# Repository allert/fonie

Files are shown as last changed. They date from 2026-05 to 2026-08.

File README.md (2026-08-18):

# 🎵 Fonie - RFID Spotify Player

ESP32 + Raspberry Pi + PN532 NFC reader = automated Spotify playback

## Hardware
- **ESP32 WROOM** - RFID polling via I2C
- **PN532** - NFC/RFID reader (I2C mode)
- **Raspberry Pi 4** - Flask web UI + Spotify integration

## Quick Start

### Fresh Pi Setup
```bash
git clone https://github.com/YOUR_USERNAME/fonie.git
cd fonie
chmod +x setup.sh
./setup.sh
```

### Manual Setup
1. Raspberry Pi OS 64-bit
2. `pip3 install -r requirements.txt`
3. Edit `.env` with Spotify credentials
4. `systemctl start fonie`
5. Visit `http://fonie.local`

## Files
- `app.py` - Flask backend
- `setup.sh` - Automated setup script
- `templates/index.html` - Web UI
- `esp32/esp.ino` - ESP32 firmware

## Configuration
1. Get Spotify API credentials from [developer.spotify.com](https://developer.spotify.com)
2. Set in `.env`:
```
   SPOTIFY_CLIENT_ID=...
   SPOTIFY_CLIENT_SECRET=...
```

## ESP32 JSON Protocol
```json
{"event":"TAG_ON","uid":"4F02FB46F6180"}
{"event":"TAG_OFF","uid":"4F02FB46F6180"}
```

## License
MIT

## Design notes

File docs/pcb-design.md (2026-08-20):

# Fonie — Custom Carrier PCB Design Specification 🛠️📐

This document outlines the complete schematic architecture, component selection (BOM), connector layout, and KiCad design guide for creating a single, professional **Fonie Mainboard Carrier PCB**.

---

## 🎯 Objectives & Benefits

1. **Zero Point-to-Point Wiring Harnesses:** Replaces loose wires, crimp pins, and protoboards with a clean 2-layer PCB.
2. **Direct Raspberry Pi 4 Docking:** Features a female 2×20 GPIO socket header that docks directly onto the Pi 4.
3. **Integrated Compute Nodes:** Sockets/footprints for:
   - **RP2040 Zero** (Waveshare module or stamp footprint)
   - **ESP32-C3 SuperMini** (or ESP32-C3-WROOM module)
   - **INA226 I2C Battery Telemetry Sensor**
4. **Onboard Power Management:**
   - Onboard Pololu 2808 soft switch connector / circuit
   - High-efficiency 5V 3A Synchronous Step-Down Buck Converter (e.g., MP2307 / TPS54331)
5. **Clean Polarized Connectors:**
   - **JST-PH 2.0mm / 2.54mm headers** for 5× Front Buttons, NeoPixel Matrix, NeoPixel Ring, Left/Right Surround LED Strips, and PN532 NFC scanner.

---

## 🏗️ Schematic Block Diagram

```
                 3S Li-ion Battery Pack (9.0V – 12.6V)
                                │
                                ▼
                       ┌────────────────┐
                       │  INA226 Sensor │  (I2C to Pico)
                       └───────┬────────┘
                               │
                               ▼
                       ┌────────────────┐
                       │  Pololu 2808   │  ◄── Vol Up Button (A pin)
                       │  Soft Switch   │  ◄── Pico GP14 (OFF pin)
                       └───────┬────────┘
                               │ Switched 12V (VOUT)
                               ▼
            ┌──────────────────┴──────────────────┐
            │                                     │
            ▼                                     ▼
   ┌─────────────────┐                   ┌──────────────────┐
   │ 5V 3A Buck Reg  │                   │ Merus Amp Hat /  │
   │ (TPS54331/MP2307)                   │ DC Barrel Jack   │
   └────────┬────────┘                   └──────────────────┘
            │ 5.1V Rail
            ├──────────────────────┬──────────────────────┐
            ▼                      ▼                      ▼
    Raspberry Pi 4 2×20      RP2040 Zero            ESP32-C3
   (GPIO Pins 2/4 + GND)    (5V & GND Pins)        (5V & GND Pins)
```

---

## 📌 Connector & Pin Routing Netlist

### 1. Raspberry Pi 4 (2×20 Header - Female Socket)
* **Pin 2, 4 (+5V):** Connected to Onboard 5.1V Buck Converter Output
* **Pin 6, 9, 14, 20, 25, 30, 34, 39 (GND):** Common Ground Plane
* **Pin 8 (GPIO 14 - UART0 TX):** Routed to RP2040 Pico `GP1` (RX)
* **Pin 10 (GPIO 15 - UART0 RX):** Routed to RP2040 Pico `GP0` (TX)
* **Pin 15 (GPIO 22 - Poweroff Sense):** Routed to RP2040 Pico `GP8`
* **Pin 32 (GPIO 12 - UART5 TX):** Routed to ESP32-C3 `IO20` (RX)
* **Pin 33 (GPIO 13 - UART5 RX):** Routed to ESP32-C3 `IO21` (TX)

### 2. RP2040 Pico Module (Sockets / Castellated Stamp)
* **GP0 (TX):** → Pi GPIO 15 (RX)
* **GP1 (RX):** ← Pi GPIO 14 (TX)
* **GP2:** → JST Connector: NeoPixel Ring Data (24 LEDs)
* **GP3:** → JST Connector: NeoPixel 8×8 Matrix Data (64 LEDs)
* **GP4:** → JST Connector: Left Surround LED Strip (26 LEDs)
* **GP5:** → JST Connector: Right Surround LED Strip (26 LEDs)
* **GP6 (SDA), GP7 (SCL):** → INA226 Sensor Module
* **GP8:** ← Pi GPIO 22 (Shutdown Sense)
* **GP14:** → Pololu 2808 `OFF` Pin
* **GP15:** ← JST Connector: Volume Down Button
* **GP26:** ← JST Connector: Volume Up Button (+ routed to Pololu Pin `A`)
* **GP27:** ← JST Connector: Next / Forward Button
* **GP28:** ← JST Connector: Play / Pause Button
* **GP29:** ← JST Connector: Prev / Back Button

### 3. ESP32-C3 Module
* **IO20 (RX):** ← Pi GPIO 12 (TX)
* **IO21 (TX):** → Pi GPIO 13 (RX)
* **IO3 (SDA), IO4 (SCL):** → PN532 NFC Module (I2C Header)

---

## 📦 Bill of Materials (BOM)

| Qty | Component Description | Footprint / Package | Notes |
|:---:|:---|:---|:---|
| 1 | Custom Carrier PCB | 2-Layer 100mm × 80mm | FR4 1.6mm thickness, Green/Black silkscreen |
| 1 | 2×20 Female Header Socket | 2.54mm Pitch Through-Hole | Docks directly onto Pi 4 GPIO pins |
| 1 | MP2307 / TPS54331 5V 3A Buck | Integrated SMT / Module | Adjustable trimpot or fixed 5.1V resistors |
| 1 | Pololu 2808 Switch Header | 1×5 2.54mm Male Header | VIN, GND, VOUT, A, OFF |
| 1 | INA226 Telemetry Header | 1×4 2.54mm Female Socket | VCC, GND, SDA, SCL |
| 5 | JST-PH 3-Pin / 4-Pin Headers | 2.0mm / 2.54mm Shrouded | NeoPixels, Buttons, PN532 I2C |
| 5 | 100nF Ceramic Capacitors | 0805 SMD | Decoupling power pins |
| 2 | 10kΩ Resistors | 0805 SMD | Pull-ups / line protection |

---

## 🎨 Recommended Next Steps for KiCad Fabrication

1. **KiCad Project Setup:** Create `Fonie_Carrier_v1.0.kicad_pro` using the pin netlist above.
2. **JLCPCB / PCBWay Ordering:**
   - 2-layer PCB fabrication (~$5 for 5 boards).
   - Optional SMT Assembly (JLCPCB SMT) to pre-solder all capacitors, resistors, regulators, and JST connectors automatically!

This carrier PCB transforms Fonie into a clean, drop-in, plug-and-play hardware module! 🚀

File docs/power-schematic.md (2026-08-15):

# Fonie — Power Architecture

## Overview

Fonie runs on a custom 3S 18650 battery pack with USB-C PD charging. A Pololu 2808 soft power switch gates all downstream loads, enabling clean power-on via button press and soft shutdown from firmware.

## Power Flow Diagram

```
                USB-C PD Charger
                (15-20V input)
                      │
                      ▼
              ┌───────────────┐
              │  CC/CV Buck   │
              │  Converter    │
              │  → 12.7V out  │
              └───────┬───────┘
                      │ charge current
                      ▼
              ┌───────────────┐
              │     BMS       │
              │  3S, 20A+     │         ┌──────────────────┐
              │  w/ balancing │◄────────│  3S 18650 Pack   │
              │               │────────►│  3 × 2900mAh     │
              │  B+  P+  P-  │         │  NCA cells       │
              └──┬───┬────┬──┘         │  9.0 - 12.6V     │
                 │   │    │            └──────────────────┘
                 │   │    │
        ┌────────┘   │    └──────────────────────┐
        │            │                           │
   ┌────┴────┐       │                      Common GND
   │ INA226  │       │                      (all devices)
   │ Current │       │
   │ Sensor  │       │
   └────┬────┘       │
        │            │
        └────┬───────┘
             │ BMS P+ output (9-12.6V)
             ▼
     ┌───────────────┐
     │  Pololu 2808  │
     │  Power Switch │
     │  LV, 2-20V   │
     │  6A cont.     │
     │               │
     │  VIN ← BMS P+ │
     │  VOUT → loads │
     │  A ← button  │
     │  OFF ← GP14  │
     └───────┬───────┘
             │ VOUT (switched, 9-12.6V)
             │
        ┌────┴────────────────────┐
        │                         │
        ▼                         ▼
┌───────────────┐         ┌───────────────┐
│ InnoMaker     │         │  5V Buck      │
│ Merus Amp Hat │         │  Converter    │
│ 2×80W         │         │               │
│               │         └───────┬───────┘
│ DC in: 9-24V  │                 │ 5V
│ Powers Pi via │                 │
│ GPIO header   │           ┌─────┼─────────────┐
│               │           │     │             │
│ → Speakers    │           ▼     ▼             ▼
└───────────────┘       ┌──────┐ ┌────────┐ ┌──────┐
                        │Pico  │ │ESP32-C3│ │PN532 │
                        │VSYS  │ │VIN     │ │VCC   │
                        └──────┘ └────────┘ └──────┘
                           │
                           ▼
                     LED Ring, Matrix,
                     Strips (5V power)
```

## Components

### Battery Pack

- **Chemistry:** NCA (Nickel Cobalt Aluminum) Li-ion
- **Configuration:** 3S1P (three cells in series)
- **Cells:** 2900mAh each (BAK N18650CL-29 type)
- **Voltage range:** 9.0V (empty, 3.0V/cell) to 12.6V (full, 4.2V/cell)
- **Nominal voltage:** 11.1V (3.7V/cell)

### BMS (Battery Management System)

- **Configuration:** 3S
- **Continuous discharge rating:** 20A+
- **Features:** overcharge, overdischarge, overcurrent, short circuit protection, cell balancing
- **Separate charge/discharge paths** for simultaneous charge and playback (true pass-through)

### Charging

- **Input:** USB-C PD charger (65W+ recommended)
- **PD negotiation:** 15V or 20V (handled by charger/device)
- **CC/CV buck converter:** steps PD voltage down to 12.7V
  - CC (constant current) phase: bulk charging
  - CV (constant voltage) phase: taper charging as cells approach 4.2V/cell
- **Charging path is independent of the Pololu switch** — the CC/CV buck connects directly to the BMS charge input, so charging occurs whether the unit is on or off

### INA226 Current/Voltage Sensor

- **Position:** high-side, between battery B+ terminal and BMS B+ terminal
- **Shunt resistor:** 2mΩ (R002)
- **Measurement:**
  - Bus voltage: battery pack voltage (LSB = 1.25mV)
  - Shunt current: bidirectional (LSB = 2.5µV across shunt)
  - Positive current = discharging
  - Negative current = charging
- **I2C address:** 0x40
- **Connected to:** Pico RP2040 via Wire1 (GP6 SDA, GP7 SCL)
- **Config register:** 0x4527 (16-sample averaging, 1.1ms conversion, continuous shunt+bus)
- **Calibration register:** 25600

### Pololu 2808 Mini Pushbutton Power Switch

- **Variant:** LV (Low Voltage) with reverse voltage protection
- **Input range:** 2.2V to 20V
- **Continuous current:** 6A (at 55°C ambient)
- **Off-state current:** ~0.01µA (negligible)
- **On-resistance:** 16mΩ at 4.5V VIN

**Wiring:**

| Pololu Pin | Connection | Notes |
|---|---|---|
| VIN | BMS P+ output | 9-12.6V from battery |
| VOUT | All downstream loads | Switched power rail |
| GND | Common ground | Shared with all devices |
| Pin A | Volume Up button (other leg to GND) | A→GND = on-only operation |
| OFF | Pico GP14 | Drive HIGH to force power off |

**Behavior:**
- Pin A wired to GND via the button means pressing can only turn the switch ON, never off
- Subsequent button presses while already on have no effect (no toggle)
- Shutdown is controlled exclusively by the Pico driving the OFF pin HIGH
- When off, quiescent draw is 0.01µA — battery self-discharge is the limiting factor

### 5V Buck Converter

- **Input:** Pololu VOUT (9-12.6V)
- **Output:** 5V regulated
- **Feeds:** Pico (VSYS pin), ESP32-C3 (VIN), PN532 (VCC), all WS2812 LEDs (5V power rail)

**Caution:** Do not connect the Pico to a PC via USB while the battery is connected. USB 5V backfeeds into the buck converter output, creating two voltage sources on the same rail. This has destroyed buck converters in this project.

### InnoMaker 2×80W Merus Amp Hat

- **Amplifier IC:** Infineon MA12070P (class-D)
- **Input:** I2S from Pi (GPIO 18-21)
- **Power input:** DC barrel jack, 9-24V (connected to Pololu VOUT)
- **Pi power:** The amp hat supplies 5V to the Pi through the GPIO header from its DC input. When the amp hat is installed, the Pi does not need separate 5V power.
- **Speakers:** 2× Infinity Reference 4032 (4Ω, 4" coaxial)
- **Audio format:** 24-bit or 32-bit only (16-bit not supported)
- **Status:** Currently fried (incorrect power supply plugged into barrel jack). Replacement pending.

## SoC (State of Charge) Estimation

Implemented in Pico firmware. Combines coulomb counting with voltage-based correction.

### Method

1. **Coulomb counting:** INA226 current is integrated over time (read every 500ms). Discharge current decreases SoC, charge current increases SoC.

2. **OCV correction:** When the pack is at rest (current below 50mA for 30+ seconds), the measured voltage is compared against an 11-point NCA OCV lookup table. SoC is gently blended toward the voltage-based estimate (70% existing + 30% voltage-based).

3. **Anchor points:**
   - **Full:** When pack voltage ≥ 12.5V AND charging AND current < 150mA (CV taper detected), SoC snaps to 100%.
   - **Empty:** When pack voltage ≤ 9.1V AND not charging, SoC snaps to 0%.

### OCV Lookup Table (3S NCA pack)

| SoC | Pack Voltage |
|-----|---|
| 0% | 9.00V |
| 10% | 9.84V |
| 20% | 10.50V |
| 30% | 10.86V |
| 40% | 11.10V |
| 50% | 11.25V |
| 60% | 11.40V |
| 70% | 11.55V |
| 80% | 11.76V |
| 90% | 12.06V |
| 100% | 12.60V |

### Reporting

SoC is reported to the Pi via UART every 30 seconds and immediately on charge state changes:

```json
{"event":"SOC","level":72,"voltage":11.400,"current":350.1,"charging":false}
```

## Soft Power On/Off Sequence

### Power On

1. Unit is off — Pololu latched off, all loads unpowered, ~0.01µA draw
2. User presses volume up button
3. Button connects Pololu pin A to GND → Pololu latches ON
4. VOUT comes up → 5V buck starts → Pi, Pico, ESP32 boot
5. Pico firmware starts, begins normal operation

### Soft Shutdown

1. User long-presses volume up (3 seconds)
2. Pico detects long press (does NOT trigger normal volume up action)
3. Pico sends `{"event":"SHUTDOWN"}` to Pi over UART
4. Pi executes `sudo shutdown -h now`
5. Pico runs LED fade-out animation as visual feedback
6. Pi kernel triggers GPIO 22 HIGH via `dtoverlay=gpio-poweroff,gpiopin=22,active_low=0` upon halting
7. Pico senses GP8 HIGH (or 8s grace period fallback) → drives GP14 HIGH → Pololu OFF pin activates → power rail drops
8. Everything powers down cleanly. Battery draw returns to 0.01µA.

### Charging While Off

The CC/CV buck converter connects directly to the BMS, bypassing the Pololu. The battery charges normally whether the unit is on or off.

## Thermal Monitoring (Planned)

| Sensor | Location | Connected To | Notes |
|---|---|---|---|
| DS18B20 (1-Wire probe) | Battery pack surface | Pico GP8 | Safety cutoff if > 45°C (charge) or > 60°C (discharge) |
| RP2040 internal temp | Pico die | ADC channel 4 | `analogReadTemp()` |
| BCM2711 internal temp | Pi SoC | `vcgencmd measure_temp` | Throttles at 80°C |

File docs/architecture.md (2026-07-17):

# Fonie — System Architecture

## Overview

Fonie is a portable RFID music player for kids. Three compute nodes communicate over UART, coordinated by a Raspberry Pi 4B running a Flask web application.

```
                        ┌─────────────────────────────────────┐
                        │          Raspberry Pi 4B             │
                        │  Flask web UI · yt-dlp · mpv/aplay  │
                        │  /dev/ttyAMA2       /dev/ttyAMA5    │
                        └──────┬──────────────────┬───────────┘
                               │ UART 115200      │ UART 115200
                               │                  │
                   ┌───────────┴───┐        ┌─────┴───────────┐
                   │  ESP32-C3     │        │  RP2040 Zero    │
                   │  Super Mini   │        │  (Waveshare)    │
                   │               │        │                 │
                   │  NFC/RFID     │        │  LEDs, Buttons  │
                   │  WiFi Config  │        │  Battery Monitor│
                   │  WiFi OTA     │        │  Power Control  │
                   └───────┬───────┘        └──┬──────┬───┬───┘
                           │ I2C                │PIO   │I2C│GPIO
                   ┌───────┴───────┐     ┌─────┘  ┌───┘   └───────┐
                   │    PN532      │     │LEDs    │INA226   │Buttons
                   │  NFC Module   │     │        │         │(×5)
                   └───────────────┘     │        │         │
                                    ┌────┴────┐   │    ┌────┴────┐
                                    │Ring 24  │   │    │Prev     │
                                    │Matrix 64│   │    │Play     │
                                    │Strip L  │   │    │Next     │
                                    │Strip R  │   │    │Vol+     │
                                    │RGB ×1   │   │    │Vol-     │
                                    └─────────┘   │    └─────────┘
                                           ┌──────┴──────┐
                                           │  INA226     │
                                           │  Current &  │
                                           │  Voltage    │
                                           └──────┬──────┘
                                                  │
                                           ┌──────┴──────┐
                                           │ 3S 18650    │
                                           │ Battery     │
                                           │ + BMS       │
                                           └─────────────┘
```

## Compute Nodes

### Raspberry Pi 4B — The Brain

Runs all high-level logic: music playback, web interface, content management.

- **OS:** Raspberry Pi OS (64-bit)
- **Application:** `app.py` — Flask web server (systemd service: `fonie.service`)
- **Audio:** yt-dlp downloads from YouTube Music (Premium cookies via Chromium), playback via mpv/aplay through I2S to InnoMaker Merus Amp Hat
- **Communication:** two hardware UARTs to the MCUs
  - `/dev/ttyAMA2` (uart2, GPIO0/1) → ESP32-C3
  - `/dev/ttyAMA5` (uart5, GPIO12/13) → RP2040
- **Device tree overlays** (`/boot/firmware/config.txt`):
  ```
  dtoverlay=merus-amp
  dtoverlay=uart2
  dtoverlay=uart5
  ```
  Note: `dtoverlay=uart4` (GPIO8/9) conflicts with the merus-amp overlay and cannot be used.

### ESP32-C3 Super Mini — NFC Handler

Single job: detect RFID tags and send events to the Pi.

- **Framework:** Arduino (elechouse PN532 library)
- **NFC:** PN532 module over I2C (GPIO3 SDA, GPIO4 SCL)
- **Pi UART:** HardwareSerial(1) on GPIO20 (RX) / GPIO21 (TX), 115200 baud
- **USB Serial:** debug output at 115200 baud
- **Planned:** WiFi captive portal for network config, ArduinoOTA for firmware updates

### RP2040 Zero (Waveshare) — LED/Button/Power Controller

Drives all user-facing I/O, monitors battery, and manages power state.

- **Framework:** Arduino (Earle Philhower core)
- **LEDs:** 5 NeoPixel outputs via PIO (ring, matrix, two speaker strips, onboard RGB)
- **Buttons:** 5 buttons with INPUT_PULLDOWN, read via polling with debounce
- **Battery:** INA226 over I2C (Wire1) for voltage/current, SoC via coulomb counting + NCA OCV lookup
- **Power:** Pololu 2808 OFF pin for soft shutdown
- **Pi UART:** Serial1 on GP0 (TX) / GP1 (RX), 115200 baud
- **USB Serial:** debug output at 115200 baud
- **Animation engine:** 60fps state machine (OFF, TAG_ON_BURST, PLAYING, PAUSED, TAG_OFF_FADE, VOLUME)

## Communication Protocol

All inter-device communication is newline-delimited JSON over UART at 115200 baud.

### ESP32-C3 → Pi

```json
{"event":"READY"}
{"event":"TAG_ON","uid":"04A2F3B1"}
{"event":"TAG_OFF","uid":"04A2F3B1"}
{"event":"ERROR","msg":"No PN532 found"}
```

### Pi → Pico

```json
{"event":"READY"}
{"event":"IDLE"}
{"event":"TAG_ON","mapped":true}
{"event":"TAG_OFF"}
{"event":"TAG_UNKNOWN"}
{"event":"PLAYING","r":0,"g":200,"b":200}
{"event":"PAUSED"}
{"event":"VOLUME","level":75}
{"event":"BRIGHTNESS","ring":60,"matrix":40}
```

### Pico → Pi

```json
{"event":"BUTTON","button":"play","pressed":true}
{"event":"BUTTON_ACTION","action":"pause"}
{"event":"BUTTON_ACTION","action":"resume"}
{"event":"BUTTON_ACTION","action":"next"}
{"event":"BUTTON_ACTION","action":"prev"}
{"event":"BUTTON_ACTION","action":"volume","level":85}
{"event":"SOC","level":72,"voltage":11.400,"current":350.1,"charging":false}
{"event":"SHUTDOWN"}
```

## Audio Chain

```
Pi (mpv/aplay) → I2S → InnoMaker 2×80W Merus Amp Hat → Infinity Reference 4032 (×2, 4Ω)
```

The amp hat accepts 9-24V DC input and powers the Pi through the GPIO header. Audio must be 24-bit or 32-bit (16-bit is not supported by the Merus MA12070P).

**Status:** Amp hat currently fried (wrong power supply plugged into barrel jack). Replacement pending.

## Physical Layout

Stacked from bottom to top:

1. Bottom lid of enclosure
2. 3S 18650 battery pack + BMS
3. Raspberry Pi 4B
4. InnoMaker Amp Hat (on Pi GPIO header)
5. Custom MCU board with RP2040 Zero + ESP32-C3 + PN532 + connectors

The entire stack slides into the enclosure from the bottom. This makes Pi USB ports and some Pico pins physically inaccessible once assembled.

## Firmware Update Paths

| Target | Method | Extra Hardware |
|---|---|---|
| Pi | `git pull` + `systemctl restart fonie` via SSH | None |
| ESP32-C3 | WiFi OTA (ArduinoOTA) | None |
| Pico | SWD from Pi via OpenOCD (if debug pads accessible) | 2 wires to Pi GPIO |
| Pico | UART OTA from Pi (planned) | None (uses existing UART) |

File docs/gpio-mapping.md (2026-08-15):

# Fonie — GPIO Mapping

Complete pin assignments for all three compute nodes. Verified against running firmware source code where applicable.

---

## RP2040 Zero (Waveshare)

Source of truth: `firmware/pico/src/main.cpp`

### Assigned Pins

| GPIO | Function | Direction | Protocol | Notes |
|---|---|---|---|---|
| GP0 | UART TX → Pi | OUT | Serial1, 115200 | `Serial1.setTX(0)` |
| GP1 | UART RX ← Pi | IN | Serial1, 115200 | `Serial1.setRX(1)` |
| GP2 | LED Ring data | OUT | PIO / WS2812 | 24 LEDs, 70mm ring around NFC scanner |
| GP3 | LED Matrix data | OUT | PIO / WS2812 | 64 LEDs, 8×8 matrix |
| GP4 | LED Strip L data | OUT | PIO / WS2812 | **NEW — not yet in firmware.** Speaker L surround |
| GP5 | LED Strip R data | OUT | PIO / WS2812 | **NEW — not yet in firmware.** Speaker R surround |
| GP6 | INA226 I2C SDA | I/O | Wire1, addr 0x40 | `Wire1.setSDA(6)` |
| GP7 | INA226 I2C SCL | OUT | Wire1 | `Wire1.setSCL(7)` |
| GP8 | Pi Shutdown Sense | IN | Digital, INPUT_PULLDOWN | Signals Pi shutdown complete (`dtoverlay=gpio-poweroff` from Pi GPIO 22) |
| GP14 | Pololu OFF | OUT | Digital | **NEW — not yet in firmware.** Drive HIGH to cut power |
| GP15 | Button: Volume Down | IN | Digital, INPUT_PULLDOWN | HIGH when pressed |
| GP16 | Onboard RGB LED | OUT | PIO / WS2812 | Single NeoPixel on the RP2040 Zero board |
| GP26 | Button: Volume Up | IN | Digital, INPUT_PULLDOWN | HIGH when pressed. Also wired to Pololu pin A → GND |
| GP27 | Button: Forward/Next | IN | Digital, INPUT_PULLDOWN | HIGH when pressed |
| GP28 | Button: Play/Pause | IN | Digital, INPUT_PULLDOWN | HIGH when pressed |
| GP29 | Button: Back/Prev | IN | Digital, INPUT_PULLDOWN | HIGH when pressed |

### Inaccessible Pins

| GPIO | Reason |
|---|---|
| GP9 | Blocked by header mounting in enclosure |
| GP10 | Blocked by header mounting in enclosure |
| GP11 | Blocked by header mounting in enclosure |
| GP12 | Blocked by header mounting in enclosure |
| GP13 | Blocked by header mounting in enclosure |

### Reserved Pins (Pico Internal)

| GPIO | Function |
|---|---|
| GP23 | SMPS power save mode |
| GP24 | VBUS sense |
| GP25 | Onboard LED (directly on RP2040 chip, separate from WS2812 on GP16) |

### Free Pins

GP17, GP18, GP19, GP20, GP21, GP22 — six GPIOs available for future use.

### SWD Programming Pads

Located on the bottom of the RP2040 Zero board (may be difficult to access depending on mounting).

| Pad | Function | Notes |
|-----|---|---|
| SWDIO | Serial Wire Data I/O | Connect to a Pi GPIO for OpenOCD flashing |
| SWCLK | Serial Wire Clock | Connect to a Pi GPIO for OpenOCD flashing |
| GND | Ground | Already shared with Pi via power rails |

---

## ESP32-C3 Super Mini

Source of truth: `firmware/esp32/src/main.cpp`

### Assigned Pins

| GPIO | Function | Direction | Protocol | Notes |
|---|---|---|---|---|
| 3 | PN532 I2C SDA | I/O | Wire, default addr | `Wire.begin(3, 4)` |
| 4 | PN532 I2C SCL | OUT | Wire | |
| 20 | UART RX ← Pi | IN | HardwareSerial(1), 115200 | `RpiSerial.begin(115200, SERIAL_8N1, 20, 21)` |
| 21 | UART TX → Pi | OUT | HardwareSerial(1), 115200 | |

### Notes

- `Serial` (USB CDC) is used for debug output at 115200 baud
- `HardwareSerial RpiSerial(1)` uses UART1 — the C3 only exposes UART0 (USB) and UART1
- No PN532 reset pin is used in the current firmware (removed during C3 port; the WROOM version used GPIO15 for reset)

---

## Raspberry Pi 4B

### Assigned Pins

| Pi GPIO | Physical Pin | Function | Device | Notes |
|---|---|---|---|---|
| GPIO 0 | 27 | UART2 TX → ESP32-C3 RX | `/dev/ttyAMA2` | `dtoverlay=uart2` |
| GPIO 1 | 28 | UART2 RX ← ESP32-C3 TX | `/dev/ttyAMA2` | |
| GPIO 12 | 32 | UART5 TX → Pico GP1 (RX) | `/dev/ttyAMA5` | `dtoverlay=uart5` |
| GPIO 13 | 33 | UART5 RX ← Pico GP0 (TX) | `/dev/ttyAMA5` | |
| GPIO 18 | 12 | I2S BCLK | Merus amp hat | `dtoverlay=merus-amp` |
| GPIO 19 | 35 | I2S LRCLK | Merus amp hat | |
| GPIO 20 | 38 | I2S DIN | Merus amp hat | |
| GPIO 21 | 40 | I2S DOUT | Merus amp hat | |

### Planned Pins

| Pi GPIO | Function | Notes |
|---|---|---|
| TBD | SWDIO → Pico debug pad | For OpenOCD flashing of Pico firmware |
| TBD | SWCLK → Pico debug pad | For OpenOCD flashing of Pico firmware |

### Known Conflicts

- `dtoverlay=uart4` (GPIO 8/9) conflicts with `dtoverlay=merus-amp` — do not use.
- The InnoMaker amp hat consumes GPIO 18-21 for I2S. These pins pass through the hat's header but are not available for other functions.

### config.txt

```
[all]
enable_uart=1
dtoverlay=merus-amp
dtoverlay=uart2
dtoverlay=uart5
```

### UART Wiring Summary

```
Pi GPIO 0  (pin 27) ──TX──→ ESP32-C3 GPIO 20 (RX)
Pi GPIO 1  (pin 28) ←─RX─── ESP32-C3 GPIO 21 (TX)

Pi GPIO 12 (pin 32) ──TX──→ Pico GP1 (RX)
Pi GPIO 13 (pin 33) ←─RX─── Pico GP0 (TX)
```

Both UARTs run at 115200 baud, 8N1.

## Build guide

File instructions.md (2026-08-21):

# Fonie — Monorepo Setup Briefing

## What is Fonie?

Fonie is a kids' RFID music player. A child places an RFID tag on the scanner, and the associated music starts playing. It's a battery-powered portable unit with physical buttons, LED feedback, and a Flask web UI for management.

## Version & Build Bumping Routine

Every feature release, bug fix, or firmware update MUST follow this version bumping routine:
1. **Raspberry Pi App:** Update `APP_VERSION = 'X.Y.Z'` in `app.py`.
2. **RP2040 Pico Firmware:** Update `#define FIRMWARE_VERSION "X.Y.Z"` in `firmware/pico/src/main.cpp`.
3. **ESP32 Firmware:** Update `#define FIRMWARE_VERSION "X.Y.Z"` in `firmware/esp32/src/main.cpp` when ESP32 code changes.
4. **Handshake Verification:** Ensure `pico_connect_internal()` and `serial_listener()` issue `{"event":"PING"}` on connect so `pico_version` and `esp32_version` populate in `/api/debug` & Web UI.
5. **Git Commit Message:** Include version number in release commit message (e.g. `bump: update version to v1.2.0`).

## Hardware Architecture

Three compute nodes communicate over UART:

- **Raspberry Pi 4B** — Main brain. Runs a Python/Flask web UI, handles music playback, manages yt-dlp downloads. Communicates with both MCUs over UART (`/dev/ttyAMA0` + `/dev/ttyAMA1`).
- **RP2040 Zero** (Waveshare) — Button/LED/battery controller. Reads 5 physical buttons, drives 4 NeoPixel LED outputs (ring, matrix, two speaker strips), monitors battery via INA226 over I2C, and handles the Pololu soft power switch. Arduino framework.
- **ESP32-C3** — NFC/RFID handler (PN532 over I2C) and WiFi configuration portal. Arduino framework.

### Communication Protocol

All inter-device communication is JSON over UART at 115200 baud. Example events:

```
Pi → Pico:  {"event":"PLAYING","r":0,"g":200,"b":200}
Pico → Pi:  {"event":"BUTTON_ACTION","action":"next"}
Pico → Pi:  {"event":"SOC","level":72,"voltage":11.4,"current":350.2,"charging":false}
ESP → Pi:   {"event":"TAG_ON","uid":"04:A2:F3:B1","mapped":true}
```

## Repository Structure

The Pi code stays at the repo root (the repo already lives on the Pi and the systemd service points at it — moving files would break the running system). Firmware and tooling go in subdirectories.

```
fonie/                               # Existing git repo on the Pi
│
│  # ── Pi files (stay at root) ─────────────────────────────────
├── app.py                           # Main Flask application
├── requirements.txt
├── settings.json                    # Runtime config (gitignored)
├── settings.example.json            # Template with defaults (committed)
├── rfid_mappings.json               # Tag→music mappings (gitignored, runtime data)
├── cert.pem / key.pem              # SSL certs (gitignored, never commit)
├── templates/                       # Flask HTML templates
├── sounds/                          # Sound effect WAVs
├── media/                           # Downloaded music (gitignored)
├── tests/                           # Pi test scripts
│   ├── test.py
│   ├── test_account.py
│   ├── test_search.py
│   ├── test_uart.py
│   └── testplay.py
│
│  # ── New directories ─────────────────────────────────────────
├── firmware/
│   ├── pico/                        # RP2040 Zero — PlatformIO/Arduino
│   │   ├── platformio.ini
│   │   ├── openocd-pi-swd.cfg      # OpenOCD config for Pi-as-SWD-adapter
│   │   ├── src/
│   │   │   └── main.cpp
│   │   └── lib/
│   │
│   ├── esp32/                       # ESP32-C3 — PlatformIO/Arduino
│   │   ├── platformio.ini
│   │   ├── src/
│   │   │   └── main.cpp
│   │   └── lib/
│   │
│   └── shared/                      # Shared between both MCUs
│       └── protocol.h               # Event names, JSON keys, constants
│
├── system/                          # systemd service file
│   └── fonie.service
│
├── scripts/                         # Deployment & OTA tooling
│   ├── deploy-pi.sh
│   ├── deploy-pico.sh
│   ├── deploy-esp32.sh
│   └── pico_uart_flash.py          # Future: UART OTA for Pico
│
├── docs/
│   ├── architecture.md
│   ├── gpio-mapping.md
│   └── power-schematic.md
│
└── .gitignore
```

**`.gitignore`:**

```
media/
rfid_mappings.json
settings.json
cert.pem
key.pem
__pycache__/
.pio/
```

## PlatformIO Configuration

### Pico (`firmware/pico/platformio.ini`)

```ini
[env:pico]
platform = raspberrypi
board = pico
framework = arduino
lib_extra_dirs = ../shared

; Local USB upload (from dev PC)
upload_protocol = picotool

[env:pico_swd]
platform = raspberrypi
board = pico
framework = arduino
lib_extra_dirs = ../shared

; Remote SWD upload via Pi + OpenOCD
upload_protocol = custom
upload_command =
    openocd
    -f ${PROJECT_DIR}/openocd-pi-swd.cfg
    -c "program ${BUILD_DIR}/firmware.elf verify reset exit"
```

### ESP32-C3 (`firmware/esp32/platformio.ini`)

```ini
[env:esp32c3]
platform = espressif32
board = esp32-c3-devkitm-1
framework = arduino
lib_extra_dirs = ../shared

; Local serial upload (from dev PC)
upload_port = /dev/ttyUSB0

[env:esp32c3_ota]
platform = espressif32
board = esp32-c3-devkitm-1
framework = arduino
lib_extra_dirs = ../shared

; Remote WiFi OTA upload
upload_protocol = espota
upload_port = fonie-esp32.local
```

## Pico RP2040 Zero — Complete GPIO Mapping

| GPIO | Function | Protocol / Notes |
|---|---|---|
| GP0  | UART TX → Pi | Serial1, 115200 baud |
| GP1  | UART RX ← Pi | Serial1, 115200 baud |
| GP2  | LED Ring data | PIO / WS2812, 24 LEDs, 70mm ring |
| GP3  | LED Matrix data | PIO / WS2812, 64 LEDs, 8×8 matrix |
| GP4  | LED Strip L data | PIO / WS2812 (NEW — speaker L) |
| GP5  | LED Strip R data | PIO / WS2812 (NEW — speaker R) |
| GP6  | INA226 I2C SDA | Wire1, addr 0x40 |
| GP7  | INA226 I2C SCL | Wire1 |
| GP8  | *free* | |
| GP9  | **INACCESSIBLE** | Blocked by header/mounting |
| GP10 | **INACCESSIBLE** | Blocked by header/mounting |
| GP11 | **INACCESSIBLE** | Blocked by header/mounting |
| GP12 | **INACCESSIBLE** | Blocked by header/mounting |
| GP13 | **INACCESSIBLE** | Blocked by header/mounting |
| GP14 | Pololu OFF pin | NEW — drive HIGH to cut power |
| GP15 | Button: Volume Down | INPUT_PULLDOWN, HIGH = pressed |
| GP16 | Onboard RGB LED | Single NeoPixel |
| GP17–22 | *free* | |
| GP23 | RESERVED (SMPS mode) | Pico internal |
| GP24 | RESERVED (VBUS sense) | Pico internal |
| GP25 | RESERVED (Onboard LED) | Pico internal |
| GP26 | Button: Volume Up | INPUT_PULLDOWN + Pololu A→GND |
| GP27 | Button: Forward/Next | INPUT_PULLDOWN, HIGH = pressed |
| GP28 | Button: Play/Pause | INPUT_PULLDOWN, HIGH = pressed |
| GP29 | Button: Back/Prev | INPUT_PULLDOWN, HIGH = pressed |

### SWD Programming Pads (bottom of board)

| Pad | Function |
|-----|---|
| TP2 | SWCLK → Pi GPIO (for OpenOCD flashing) |
| TP3 | SWDIO → Pi GPIO (for OpenOCD flashing) |
| TP4 | GND (already shared with Pi) |

## Current Pico Firmware (`firmware/pico/src/main.cpp`)

```cpp
#include <Adafruit_NeoPixel.h>
#include <Wire.h>

// ── Pin config ────────────────────────────────────────────────────────────────
#define RGB_PIN     16
#define RING_PIN     2
#define MATRIX_PIN   3
#define RING_LEDS   24
#define MATRIX_LEDS 64

// INA226 I2C (same pins as old MAX17043)
#define INA226_ADDR 0x40
#define INA226_SDA  6
#define INA226_SCL  7

// INA226 registers
#define INA226_REG_CONFIG    0x00
#define INA226_REG_SHUNT     0x01
#define INA226_REG_BUS       0x02
#define INA226_REG_CALIB     0x05

// Shunt resistor value (R100 = 100mΩ = 0.1Ω)
#define SHUNT_OHMS        0.002f
// Pack capacity in mAh (3 x 2900mAh in series)
#define PACK_CAPACITY_MAH 2900.0f
// Current sense LSB with R100 shunt: 2.5uV / 0.1Ω = 25uA per LSB
#define CURRENT_LSB_MA    0.1f     // mA per LSB (after calibration)
// Bus voltage LSB is always 1.25mV
#define BUS_VOLTAGE_LSB   0.00125f // V per LSB

// 3S pack voltage thresholds
#define PACK_FULL_V       12.6f
#define PACK_EMPTY_V       9.0f   // 3.0V per cell
#define PACK_REST_I_MA    50.0f   // below this = at rest (no significant load/charge)
#define CHARGE_TAPER_MA   150.0f  // CV phase taper threshold → set SoC = 100%

// Buttons (INPUT_PULLDOWN, HIGH when pressed)
#define BTN_PREV    29
#define BTN_PLAY    28
#define BTN_NEXT    27
#define BTN_VOLUP   26
#define BTN_VOLDOWN 15

#define DEBOUNCE_MS  50
#define VOL_STEP      5
#define VOL_MIN       0
#define VOL_MAX     100

Adafruit_NeoPixel rgb(1,            RGB_PIN,    NEO_GRB + NEO_KHZ800);
Adafruit_NeoPixel ring(RING_LEDS,   RING_PIN,   NEO_GRB + NEO_KHZ800);
Adafruit_NeoPixel matrix(MATRIX_LEDS, MATRIX_PIN, NEO_GRB + NEO_KHZ800);

// ── State machine ─────────────────────────────────────────────────────────────
enum State { S_OFF, S_TAG_ON_BURST, S_PLAYING, S_PAUSED, S_TAG_OFF_FADE, S_VOLUME };
State currentState   = S_OFF;
State preVolumeState = S_OFF;

unsigned long stateStart = 0;
unsigned long lastFrame  = 0;

float   spinPos    = 0.0;
float   breathVal  = 1.0;
int     breathDir  = -1;
float   fadeVal    = 1.0;
int     volumeLevel = 80;
uint8_t animR = 0, animG = 200, animB = 200;
float   waveOffset = 0.0;

// ── SoC / INA226 state ────────────────────────────────────────────────────────
float   socPercent   = 50.0f;  // initial guess until we correct from voltage
bool    socValid     = false;
float   packVoltage  = 0.0f;
float   packCurrentMA = 0.0f;  // positive = discharging, negative = charging
bool    isCharging   = false;
bool    lastCharging = false;

unsigned long lastSoCRead    = 0;
unsigned long lastSoCReport  = 0;
unsigned long lastRestStart  = 0;
bool          atRest         = false;

#define SOC_READ_INTERVAL_MS    500    // read INA226 every 500ms
#define SOC_REPORT_INTERVAL_MS  30000  // report to Pi every 30s

// ── Buttons ───────────────────────────────────────────────────────────────────
struct Button {
  uint8_t pin;
  const char* name;
  bool state;
  bool lastRaw;
  unsigned long lastChange;
};

Button buttons[] = {
  { BTN_PREV,    "prev",   false, false, 0 },
  { BTN_PLAY,    "play",   false, false, 0 },
  { BTN_NEXT,    "next",   false, false, 0 },
  { BTN_VOLUP,   "vol_up", false, false, 0 },
  { BTN_VOLDOWN, "vol_dn", false, false, 0 },
};
#define NUM_BUTTONS 5

// ── INA226 ────────────────────────────────────────────────────────────────────
void ina226_writeReg(uint8_t reg, uint16_t val) {
  Wire1.beginTransmission(INA226_ADDR);
  Wire1.write(reg);
  Wire1.write((val >> 8) & 0xFF);
  Wire1.write(val & 0xFF);
  Wire1.endTransmission();
}

uint16_t ina226_readReg(uint8_t reg) {
  Wire1.beginTransmission(INA226_ADDR);
  Wire1.write(reg);
  Wire1.endTransmission(false);
  Wire1.requestFrom(INA226_ADDR, 2);
  if (Wire1.available() < 2) return 0;
  uint16_t val = (Wire1.read() << 8) | Wire1.read();
  return val;
}

void ina226_init() {
  Wire1.setSDA(INA226_SDA);
  Wire1.setSCL(INA226_SCL);
  Wire1.begin();

  // Config: avg 16 samples, 1.1ms conversion, continuous shunt+bus
  // BADC=SADC=0b0101 (1.1ms), AVG=0b011 (16), MODE=111 (continuous)
  ina226_writeReg(INA226_REG_CONFIG, 0x4527);

  // Calibration register: Cal = 0.00512 / (CurrentLSB * Rshunt)
  // CurrentLSB = 0.025mA = 0.000025A
  // Cal = 0.00512 / (0.000025 * 0.1) = 2048
  ina226_writeReg(INA226_REG_CALIB, 25600);

  Serial.println("INA226 init done");
}

bool ina226_scan() {
  Wire1.beginTransmission(INA226_ADDR);
  return Wire1.endTransmission() == 0;
}

// Returns bus voltage in volts
float ina226_voltage() {
  uint16_t raw = ina226_readReg(INA226_REG_BUS);
  return raw * BUS_VOLTAGE_LSB;
}

// Returns current in mA (positive = discharging, negative = charging)
float ina226_current() {
  int16_t raw = (int16_t)ina226_readReg(INA226_REG_SHUNT);
  // Shunt register LSB = 2.5uV
  // Current = (raw * 2.5uV) / Rshunt
  float shuntVoltage_uV = raw * 2.5f;
  return (shuntVoltage_uV / 1000.0f) / SHUNT_OHMS;
}

// ── SoC from OCV curve (3S NCA Li-ion, rest state only) ──────────────────────
// 11-point lookup table at 10% SoC intervals, voltages in V for 3S pack
// Based on standard NCA OCV curve (BAK N18650CL-29 type)
static const float OCV_V[11] = {
   9.00f,  // 0%
   9.84f,  // 10%
  10.50f,  // 20%
  10.86f,  // 30%
  11.10f,  // 40%
  11.25f,  // 50%
  11.40f,  // 60%
  11.55f,  // 70%
  11.76f,  // 80%
  12.06f,  // 90%
  12.60f,  // 100%
};

float voltageToSoC(float v) {
  if (v <= OCV_V[0])  return 0.0f;
  if (v >= OCV_V[10]) return 100.0f;
  for (int i = 0; i < 10; i++) {
    if (v <= OCV_V[i + 1]) {
      float t = (v - OCV_V[i]) / (OCV_V[i + 1] - OCV_V[i]);
      return (i + t) * 10.0f;
    }
  }
  return 100.0f;
}

// ── SoC update (coulomb counting + correction) ────────────────────────────────
void updateSoC() {
  unsigned long now = millis();
  if (now - lastSoCRead < SOC_READ_INTERVAL_MS) return;

  float dt_h = (now - lastSoCRead) / 3600000.0f;  // ms to hours
  lastSoCRead = now;

  packVoltage   = ina226_voltage();
  packCurrentMA = ina226_current();
  isCharging    = packCurrentMA < -PACK_REST_I_MA;

  // Immediate report on charging state change
  if (isCharging != lastCharging) {
    lastCharging = isCharging;
    socValid = true;
    reportSoC();
  }

  // Coulomb counting: discharge = positive current = decreases SoC
  // charge = negative current = increases SoC
  float deltaSoC = (-packCurrentMA * dt_h / PACK_CAPACITY_MAH) * 100.0f;
  socPercent = constrain(socPercent + deltaSoC, 0.0f, 100.0f);

  // Rest state detection
  if (abs(packCurrentMA) < PACK_REST_I_MA) {
    if (!atRest) { atRest = true; lastRestStart = now; }
    // Correct from voltage after 30s at rest
    if (now - lastRestStart > 30000) {
      float voltSoC = voltageToSoC(packVoltage);
      // Gentle correction — blend toward voltage-based SoC
      socPercent = socPercent * 0.7f + voltSoC * 0.3f;
      Serial.print("OCV correction: ");
      Serial.print(voltSoC, 1); Serial.println("%");
    }
  } else {
    atRest = false;
    lastRestStart = now;
  }

  // Full charge anchor: CV phase detected (high voltage + tapering current)
  if (packVoltage >= PACK_FULL_V - 0.1f && isCharging &&
      abs(packCurrentMA) < CHARGE_TAPER_MA) {
    socPercent = 100.0f;
    Serial.println("CV taper detected -> SoC = 100%");
  }

  // Empty anchor
  if (packVoltage <= PACK_EMPTY_V + 0.1f && !isCharging) {
    socPercent = 0.0f;
  }

  // Report to Pi periodically
  if (now - lastSoCReport >= SOC_REPORT_INTERVAL_MS || !socValid) {
    socValid = true;
    reportSoC();
  }
}

void reportSoC() {
  lastSoCReport = millis();
  String msg = "{\"event\":\"SOC\""
               ",\"level\":"    + String((int)socPercent) +
               ",\"voltage\":"  + String(packVoltage, 3) +
               ",\"current\":"  + String(packCurrentMA, 1) +
               ",\"charging\":" + (isCharging ? "true" : "false") + "}";
  Serial1.println(msg);
  Serial.println(msg);
}

// ── 5x3 pixel font ────────────────────────────────────────────────────────────
const uint8_t digitFont[10][5] = {
  {0b111,0b101,0b101,0b101,0b111},{0b010,0b110,0b010,0b010,0b111},
  {0b111,0b001,0b111,0b100,0b111},{0b111,0b001,0b111,0b001,0b111},
  {0b101,0b101,0b111,0b001,0b001},{0b111,0b100,0b111,0b001,0b111},
  {0b111,0b100,0b111,0b101,0b111},{0b111,0b001,0b001,0b001,0b001},
  {0b111,0b101,0b111,0b101,0b111},{0b111,0b101,0b111,0b001,0b111},
};

// ── Matrix helpers ────────────────────────────────────────────────────────────
int matrixPixel(int x, int y) {
  return (y % 2 == 0) ? y * 8 + x : y * 8 + (7 - x);
}
void matrixSet(int x, int y, uint8_t r, uint8_t g, uint8_t b) {
  if (x < 0 || x >= 8 || y < 0 || y >= 8) return;
  matrix.setPixelColor(matrixPixel(x, y), matrix.Color(r, g, b));
}
void matrixClear() { matrix.clear(); }

void drawDigit(int d, int startX, int startY, uint8_t r, uint8_t g, uint8_t b) {
  for (int row = 0; row < 5; row++) {
    uint8_t bits = digitFont[d][row];
    for (int col = 0; col < 3; col++)
      if (bits & (1 << (2 - col))) matrixSet(startX + col, startY + row, r, g, b);
  }
}

void drawSoC(int soc) {
  matrixClear();
  uint8_t r, g, b = 0;
  if (isCharging)    { r = 0;   g = 100; b = 200; }
  else if (soc > 50) { r = 0;   g = 255; b = 0;   }
  else if (soc > 20) { r = 255; g = 180; b = 0;   }
  else               { r = 255; g = 0;   b = 0;   }

  if (soc >= 100) {
    drawDigit(1, 0, 1, r, g, b);
    drawDigit(0, 4, 1, r, g, b);
  } else if (soc < 10) {
    drawDigit(soc, 3, 1, r, g, b);
  } else {
    drawDigit(soc / 10, 1, 1, r, g, b);
    drawDigit(soc % 10, 5, 1, r, g, b);
  }
  matrixSet(7, 5, r, g, b);
  matrixSet(6, 6, r, g, b);
  matrixSet(7, 7, r, g, b);
  matrix.show();

  int litLeds = (soc * RING_LEDS) / 100;
  ring.clear();
  for (int i = 0; i < litLeds; i++) {
    float t    = (float)i / RING_LEDS;
    uint8_t lr, lg, lb = 0;
    if (isCharging) { lr = 0; lg = 100; lb = (uint8_t)(200 * t); }
    else {
      lr = t < 0.5 ? (uint8_t)(t * 2 * 80) : 255;
      lg = t < 0.5 ? 255 : (uint8_t)(255 - ((t - 0.5) * 2 * 255));
    }
    ring.setPixelColor(i, ring.Color(lr, lg, lb));
  }
  ring.show();
}

// ── Matrix animations ─────────────────────────────────────────────────────────
void drawVolumeBar(int vol) {
  matrixClear();
  int cols = (vol * 8) / 100;
  for (int x = 0; x < cols; x++) {
    uint8_t r, g, b = 0;
    if (x < 4) { r = (uint8_t)(x * 60); g = 255; }
    else        { r = 255; g = (uint8_t)(255 - ((x - 4) * 60)); }
    for (int y = 0; y < 8; y++) matrixSet(x, y, r, g, b);
  }
  matrix.show();
}

void drawMatrixWave(uint8_t r, uint8_t g, uint8_t b) {
  matrixClear();
  for (int x = 0; x < 8; x++) {
    float phase  = waveOffset + (x * 0.8);
    float s      = (sin(phase) + 1.0) / 2.0;
    int litRows  = (int)(s * 8);
    int startRow = (8 - litRows) / 2;
    for (int y = startRow; y < startRow + litRows; y++) {
      float rowFade = 1.0 - abs((y - 3.5) / 4.0) * 0.5;
      matrixSet(x, y, (uint8_t)(r*rowFade), (uint8_t)(g*rowFade), (uint8_t)(b*rowFade));
    }
  }
  matrix.show();
}

void drawMatrixCheckerboard(uint8_t r, uint8_t g, uint8_t b) {
  matrixClear();
  for (int x = 0; x < 8; x++)
    for (int y = 0; y < 8; y++)
      if ((x + y) % 2 == 0) matrixSet(x, y, r, g, b);
  matrix.show();
}

void drawMatrixBurst(float progress, uint8_t r, uint8_t g, uint8_t b) {
  matrixClear();
  float dist = progress * 5.66;
  for (int x = 0; x < 8; x++) {
    for (int y = 0; y < 8; y++) {
      float dx = x - 3.5, dy = y - 3.5;
      float d  = sqrt(dx*dx + dy*dy);
      if (d <= dist) {
        float df = 1.0 - (d / dist) * 0.5;
        matrixSet(x, y, (uint8_t)(r*df), (uint8_t)(g*df), (uint8_t)(b*df));
      }
    }
  }
  matrix.show();
}

void drawMatrixSolid(uint8_t r, uint8_t g, uint8_t b) {
  for (int i = 0; i < MATRIX_LEDS; i++)
    matrix.setPixelColor(i, matrix.Color(r, g, b));
  matrix.show();
}

// ── Helpers ───────────────────────────────────────────────────────────────────
void setRGB(uint8_t r, uint8_t g, uint8_t b) {
  rgb.setPixelColor(0, rgb.Color(r, g, b)); rgb.show();
}
void allOff() {
  ring.clear(); ring.show(); matrixClear(); matrix.show(); setRGB(0,0,0);
}

void setState(State s) {
  currentState = s;
  stateStart   = millis();
  lastFrame    = millis();
  if (s == S_OFF)          allOff();
  if (s == S_TAG_OFF_FADE) fadeVal   = 1.0;
  if (s == S_PLAYING)      { spinPos = 0; breathVal = 1.0; breathDir = -1; waveOffset = 0; }
  if (s == S_PAUSED)       { breathVal = 1.0; breathDir = -1; }
}

void overlaySoC() {
  if (!socValid) return;
  drawSoC((int)socPercent);
}

// ── Animation frames ──────────────────────────────────────────────────────────
void frameBurst() {
  unsigned long elapsed = millis() - stateStart;
  float progress = elapsed / 1200.0;
  if (progress >= 1.0) { setState(S_PLAYING); return; }
  spinPos = fmod(spinPos + 0.8, RING_LEDS);
  ring.clear();
  for (int t = 0; t < 8; t++) {
    int pos = (int)(spinPos - t + RING_LEDS * 2) % RING_LEDS;
    float tf = 1.0 - (t / 8.0);
    ring.setPixelColor(pos, ring.Color((uint8_t)(animR*tf),(uint8_t)(animG*tf),(uint8_t)(animB*tf)));
  }
  ring.show();
  drawMatrixBurst(progress, animR, animG, animB);
  overlaySoC();
  setRGB(animR/2, animG/2, animB/2);
}

void framePlaying() {
  breathVal += 0.008 * breathDir;
  if (breathVal >= 1.0)  { breathVal = 1.0;  breathDir = -1; }
  if (breathVal <= 0.5)  { breathVal = 0.5;  breathDir =  1; }
  spinPos = fmod(spinPos + 0.15, RING_LEDS);
  ring.clear();
  int tailLen = (int)(10 * breathVal);
  for (int t = 0; t < tailLen; t++) {
    int pos = (int)(spinPos - t + RING_LEDS * 2) % RING_LEDS;
    float tf = 1.0 - (float)t / tailLen;
    ring.setPixelColor(pos, ring.Color((uint8_t)(animR*tf),(uint8_t)(animG*tf),(uint8_t)(animB*tf)));
  }
  ring.show();
  waveOffset += 0.08;
  drawMatrixWave(animR, animG, animB);
  overlaySoC();
  setRGB(animR/4, animG/4, animB/4);
}

void framePaused() {
  breathVal += 0.003 * breathDir;
  if (breathVal >= 1.0)  { breathVal = 1.0;  breathDir = -1; }
  if (breathVal <= 0.3)  { breathVal = 0.3;  breathDir =  1; }
  int litLeds = (int)(RING_LEDS * breathVal);
  ring.clear();
  for (int i = 0; i < litLeds; i++)
    ring.setPixelColor(i, ring.Color(animR/2, animG/2, animB/2));
  ring.show();
  drawMatrixCheckerboard(animR, animG, animB);
  overlaySoC();
  setRGB(animR/4, animG/4, animB/4);
}

void frameFade() {
  fadeVal -= 0.025;
  if (fadeVal <= 0) { setState(S_OFF); return; }
  ring.fill(ring.Color((uint8_t)(animR*fadeVal),(uint8_t)(animG*fadeVal),(uint8_t)(animB*fadeVal)));
  ring.show();
  drawMatrixSolid((uint8_t)(animR*fadeVal),(uint8_t)(animG*fadeVal),(uint8_t)(animB*fadeVal));
  overlaySoC();
  setRGB((uint8_t)(animR*fadeVal*0.2),(uint8_t)(animG*fadeVal*0.2),(uint8_t)(animB*fadeVal*0.2));
}

void frameVolume() {
  if (millis() - stateStart > 2000) { setState(preVolumeState); return; }
  drawVolumeBar(volumeLevel);
  int litLeds = (volumeLevel * RING_LEDS) / 100;
  ring.clear();
  for (int i = 0; i < litLeds; i++) {
    float t   = (float)i / RING_LEDS;
    uint8_t r = t < 0.5 ? (uint8_t)(t*2*80) : 255;
    uint8_t g = t < 0.5 ? 255 : (uint8_t)(255-(t-0.5)*2*255);
    ring.setPixelColor(i, ring.Color(r, g, 0));
  }
  ring.show();
}

void frameOff() {
  if (socValid) drawSoC((int)socPercent);
}

// ── Event handlers ────────────────────────────────────────────────────────────
void onReady() {
  ring.fill(ring.Color(180,180,180));
  drawMatrixSolid(180,180,180);
  ring.show(); setRGB(180,180,180);
  delay(200);
  setState(S_OFF);
}

void onTagOn(bool mapped) {
  if (mapped) { animR = 0;   animG = 200; animB = 200; }
  else        { animR = 200; animG = 140; animB = 0;   }
  setState(S_TAG_ON_BURST);
}

void onPlaying(uint8_t r, uint8_t g, uint8_t b) {
  animR = r; animG = g; animB = b;
  setState(S_PLAYING);
}

void onVolume(int vol) {
  volumeLevel    = constrain(vol, VOL_MIN, VOL_MAX);
  preVolumeState = currentState;
  setState(S_VOLUME);
}

// ── JSON parser ───────────────────────────────────────────────────────────────
String extractValue(const String& json, const String& key) {
  String search = "\"" + key + "\"";
  int idx = json.indexOf(search);
  if (idx < 0) return "";
  idx = json.indexOf(':', idx + search.length());
  if (idx < 0) return "";
  idx++;
  while (idx < (int)json.length() && json[idx] == ' ') idx++;
  if (json[idx] == '"') {
    int start = idx + 1, end = json.indexOf('"', start);
    return json.substring(start, end);
  } else {
    int start = idx, end = start;
    while (end < (int)json.length() && json[end] != ',' && json[end] != '}') end++;
    return json.substring(start, end);
  }
}

void handleEvent(const String& line) {
  Serial.print("Pi: "); Serial.println(line);
  String event = extractValue(line, "event");
  if      (event == "READY" || event == "IDLE") onReady();
  else if (event == "TAG_ON")   onTagOn(extractValue(line, "mapped") == "true");
  else if (event == "TAG_OFF" || event == "TAG_UNKNOWN") setState(S_TAG_OFF_FADE);
  else if (event == "PLAYING") {
    String rs = extractValue(line, "r");
    String gs = extractValue(line, "g");
    String bs = extractValue(line, "b");
    onPlaying(
      rs.length() ? rs.toInt() : animR,
      gs.length() ? gs.toInt() : animG,
      bs.length() ? bs.toInt() : animB
    );
  }
  else if (event == "PAUSED") setState(S_PAUSED);
  else if (event == "VOLUME") {
    String lvl = extractValue(line, "level");
    if (lvl.length()) onVolume(lvl.toInt());
  }
  else if (event == "BRIGHTNESS") {
    String r = extractValue(line, "ring");
    String m = extractValue(line, "matrix");
    if (r.length()) { ring.setBrightness(r.toInt());   ring.show(); }
    if (m.length()) { matrix.setBrightness(m.toInt()); matrix.show(); }
  }
}

// ── Button handling ───────────────────────────────────────────────────────────
void sendButtonEvent(const char* name, bool pressed) {
  String msg = "{\"event\":\"BUTTON\",\"button\":\"" + String(name) +
               "\",\"pressed\":" + (pressed ? "true" : "false") + "}";
  Serial1.println(msg); Serial.println(msg);
}

void handleButtonPress(const char* name) {
  if (strcmp(name, "play") == 0) {
    if (currentState == S_PLAYING) {
      setState(S_PAUSED);
      Serial1.println("{\"event\":\"BUTTON_ACTION\",\"action\":\"pause\"}");
    } else if (currentState == S_PAUSED) {
      setState(S_PLAYING);
      Serial1.println("{\"event\":\"BUTTON_ACTION\",\"action\":\"resume\"}");
    }
  } else if (strcmp(name, "next") == 0) {
    Serial1.println("{\"event\":\"BUTTON_ACTION\",\"action\":\"next\"}");
  } else if (strcmp(name, "prev") == 0) {
    Serial1.println("{\"event\":\"BUTTON_ACTION\",\"action\":\"prev\"}");
  } else if (strcmp(name, "vol_up") == 0) {
    volumeLevel = constrain(volumeLevel + VOL_STEP, VOL_MIN, VOL_MAX);
    String msg = "{\"event\":\"BUTTON_ACTION\",\"action\":\"volume\",\"level\":" + String(volumeLevel) + "}";
    Serial1.println(msg); onVolume(volumeLevel);
  } else if (strcmp(name, "vol_dn") == 0) {
    volumeLevel = constrain(volumeLevel - VOL_STEP, VOL_MIN, VOL_MAX);
    String msg = "{\"event\":\"BUTTON_ACTION\",\"action\":\"volume\",\"level\":" + String(volumeLevel) + "}";
    Serial1.println(msg); onVolume(volumeLevel);
  }
}

void pollButtons() {
  unsigned long now = millis();
  for (int i = 0; i < NUM_BUTTONS; i++) {
    bool raw = digitalRead(buttons[i].pin) == HIGH;
    if (raw != buttons[i].lastRaw) { buttons[i].lastChange = now; buttons[i].lastRaw = raw; }
    if ((now - buttons[i].lastChange) >= DEBOUNCE_MS && raw != buttons[i].state) {
      buttons[i].state = raw;
      sendButtonEvent(buttons[i].name, raw);
      if (raw) handleButtonPress(buttons[i].name);
    }
  }
}

// ── Setup & loop ──────────────────────────────────────────────────────────────
String inputBuffer = "";

void setup() {
  Serial.begin(115200);

  rgb.begin();    rgb.setBrightness(80);
  ring.begin();   ring.setBrightness(60);
  matrix.begin(); matrix.setBrightness(40);
  allOff();
  delay(200);

  pinMode(BTN_PREV,    INPUT_PULLDOWN);
  pinMode(BTN_PLAY,    INPUT_PULLDOWN);
  pinMode(BTN_NEXT,    INPUT_PULLDOWN);
  pinMode(BTN_VOLUP,   INPUT_PULLDOWN);
  pinMode(BTN_VOLDOWN, INPUT_PULLDOWN);

  // Startup rainbow
  uint32_t colors[6] = {
    rgb.Color(200,0,0), rgb.Color(200,100,0), rgb.Color(0,200,0),
    rgb.Color(0,200,200), rgb.Color(0,0,200), rgb.Color(150,0,200)
  };
  for (int i = 0; i < 6; i++) {
    rgb.setPixelColor(0, colors[i]);
    ring.fill(colors[i]);
    for (int p = 0; p < MATRIX_LEDS; p++) matrix.setPixelColor(p, colors[i]);
    rgb.show(); ring.show(); matrix.show();
    delay(120);
  }
  allOff();

  // INA226 init
  ina226_init();
  delay(200);

  if (ina226_scan()) {
    Serial.println("INA226 found at 0x40");
    // Initial voltage-based SoC estimate
    packVoltage = ina226_voltage();
    socPercent  = voltageToSoC(packVoltage);
    socValid    = true;
    Serial.print("Initial SoC from voltage: ");
    Serial.print(socPercent, 1); Serial.println("%");
    reportSoC();
  } else {
    Serial.println("INA226 not found!");
  }

  lastSoCRead   = millis();
  lastSoCReport = millis();
  lastRestStart = millis();

  Serial1.setTX(0); Serial1.setRX(1); Serial1.begin(115200);
}

void loop() {
  // Animation frame ~60fps
  if (millis() - lastFrame >= 16) {
    lastFrame = millis();
    switch (currentState) {
      case S_TAG_ON_BURST: frameBurst();   break;
      case S_PLAYING:      framePlaying(); break;
      case S_PAUSED:       framePaused();  break;
      case S_TAG_OFF_FADE: frameFade();    break;
      case S_VOLUME:       frameVolume();  break;
      case S_OFF:          frameOff();     break;
    }
  }

  // SoC update
  updateSoC();

  // Buttons
  pollButtons();

  // UART from Pi
  while (Serial1.available()) {
    char c = (char)Serial1.read();
    if (c == '\n') {
      inputBuffer.trim();
      if (inputBuffer.length() > 0) handleEvent(inputBuffer);
      inputBuffer = "";
    } else {
      inputBuffer += c;
    }
  }
}
```

## Firmware Changes Needed for Pico

Three additions to the code above:

### 1. LED Strip Pins (GP4, GP5)

Add two new `Adafruit_NeoPixel` instances for the speaker strips. Number of LEDs TBD (short strips). Wire them into the existing animation state machine — they should mirror or complement the ring/matrix animations during playback states.

```cpp
#define STRIP_L_PIN  4
#define STRIP_R_PIN  5
#define STRIP_LEDS   10  // TBD — adjust to actual strip length

Adafruit_NeoPixel stripL(STRIP_LEDS, STRIP_L_PIN, NEO_GRB + NEO_KHZ800);
Adafruit_NeoPixel stripR(STRIP_LEDS, STRIP_R_PIN, NEO_GRB + NEO_KHZ800);
```

### 2. Pololu Soft Power OFF (GP14)

```cpp
#define POLOLU_OFF_PIN 14
```

In `setup()`:
```cpp
pinMode(POLOLU_OFF_PIN, OUTPUT);
digitalWrite(POLOLU_OFF_PIN, LOW);  // keep power alive
```

### 3. Long-Press Shutdown on Volume Up (GP26)

Detect a 3-second hold on the volume up button. When triggered:

1. Send `{"event":"SHUTDOWN"}` to Pi over UART
2. Start a fade-out animation on LEDs (visual feedback that shutdown is in progress)
3. Pi executes `sudo shutdown -h now`
4. Raspberry Pi kernel drives Pi GPIO 22 HIGH via `dtoverlay=gpio-poweroff,gpiopin=22,active_low=0` when Linux halt completes
5. Pico detects HIGH on GP8 (or 8s grace period fallback) → drives GP14 (Pololu OFF) HIGH → power rail drops → everything off cleanly

### 4. OTA via UART (future)

Add a handler for `{"event":"ENTER_OTA"}` from the Pi. When received, the Pico enters a UART firmware receive mode: a RAM-resident flash writer receives the binary in chunks, writes to flash, and reboots. This is a later addition — not needed for initial setup.

## Pololu 2808 Wiring

The Pololu Mini Pushbutton Power Switch (LV, 2.2–20V, 6A) handles soft power on/off:

| Pololu Pin | Connects To |
|---|---|
| VIN | Battery rail (BMS output, 9–12.6V) |
| VOUT | Everything downstream (5V buck, amp, etc) |
| GND | Common ground |
| Pin A | Volume Up button (other leg to GND) |
| OFF | Pico GP14 |

Pin A wired to GND via the button = **on-only** operation. The button can only turn the Pololu on, never off. Pico controls shutdown exclusively via the OFF pin.

## Power Architecture (summary)

- **USB-C PD (15–20V)** → CC/CV buck (12.7V) → BMS → 3S 18650 pack (2900mAh NCA)
- **Pololu 2808** sits between BMS output and all loads
- **Pololu VOUT** → 5V buck (logic rail for Pi, Pico, ESP32, PN532) + diode-OR to amp (12V direct)
- **INA226** shunt between battery B+ and BMS B+ (bidirectional current sense, 2mΩ shunt)
- **Pico reads INA226** via I2C (GP6/GP7) for coulomb counting + NCA OCV-based SoC estimation

## ESP32-C3 Super Mini — GPIO Mapping

| GPIO | Function |
|---|---|
| 3 | I2C SDA → PN532 |
| 4 | I2C SCL → PN532 |
| 20 | UART1 RX ← Pi TX |
| 21 | UART1 TX → Pi RX |

Libraries: elechouse `PN532_I2C` + `PN532` (not Adafruit)

### Current Firmware (`firmware/esp32/src/main.cpp`)

```cpp
#include <Wire.h>
#include <PN532_I2C.h>
#include <PN532.h>

#define SDA_PIN 3
#define SCL_PIN 4
#define RPI_TX  21   // ESP32 TX → Pi RX
#define RPI_RX  20   // ESP32 RX ← Pi TX

PN532_I2C pn532_i2c(Wire);
PN532 nfc(pn532_i2c);
HardwareSerial RpiSerial(1);   // UART1 — C3 only has UART0 and UART1 exposed

const unsigned long POLL_INTERVAL_MS   = 50;
const unsigned long REMOVAL_TIMEOUT_MS = 300;

bool tagPresent = false;
String currentUid = "";
unsigned long lastSeen = 0, lastPoll = 0;

String uidToString(uint8_t *uid, uint8_t len) {
  String s;
  for (uint8_t i = 0; i < len; i++) { if (uid[i] < 0x10) s += "0"; s += String(uid[i], HEX); }
  s.toUpperCase(); return s;
}

void setup() {
  Serial.begin(115200);                                    // USB debug
  RpiSerial.begin(115200, SERIAL_8N1, RPI_RX, RPI_TX);   // UART to Pi

  Wire.begin(SDA_PIN, SCL_PIN);
  nfc.begin();
  if (!nfc.getFirmwareVersion()) {
    Serial.println("No PN532 found");
    RpiSerial.println("{\"event\":\"ERROR\",\"msg\":\"No PN532 found\"}");
    while (1);
  }
  nfc.SAMConfig();
  Serial.println("PN532 ready");
  RpiSerial.println("{\"event\":\"READY\"}");
}

void loop() {
  unsigned long now = millis();
  if (now - lastPoll < POLL_INTERVAL_MS) return;
  lastPoll = now;

  uint8_t uid[7], uidLength;
  bool ok = nfc.readPassiveTargetID(PN532_MIFARE_ISO14443A, uid, &uidLength, 5);

  if (ok) {
    String uidStr = uidToString(uid, uidLength);
    lastSeen = now;
    if (!tagPresent) {
      tagPresent = true;
      currentUid = uidStr;
      RpiSerial.printf("{\"event\":\"TAG_ON\",\"uid\":\"%s\"}\n", currentUid.c_str());
      Serial.printf("TAG_ON %s\n", currentUid.c_str());
    } else if (uidStr != currentUid) {
      RpiSerial.printf("{\"event\":\"TAG_OFF\",\"uid\":\"%s\"}\n", currentUid.c_str());
      RpiSerial.printf("{\"event\":\"TAG_ON\",\"uid\":\"%s\"}\n", uidStr.c_str());
      currentUid = uidStr;
      Serial.printf("TAG_CHANGED %s\n", currentUid.c_str());
    }
  } else if (tagPresent && (now - lastSeen) > REMOVAL_TIMEOUT_MS) {
    RpiSerial.printf("{\"event\":\"TAG_OFF\",\"uid\":\"%s\"}\n", currentUid.c_str());
    Serial.printf("TAG_OFF %s\n", currentUid.c_str());
    tagPresent = false;
    currentUid = "";
  }
}
```

### Future: WiFi Config Portal

The ESP32-C3's WiFi is planned as a configuration backdoor. When the Pi can't connect to a known network, the C3 spins up a captive portal AP ("Fonie-Setup"). User connects, picks a WiFi network, enters the password. The C3 sends `{"event":"WIFI_CONFIG","ssid":"...","pass":"..."}` to the Pi over UART. Not yet implemented.

### OTA

WiFi OTA via ArduinoOTA — add the OTA handler to the firmware, then flash from anywhere on the same network. No extra wiring needed.

## Audio

- **Amp:** InnoMaker 2×80W Hat (currently blown — replacement pending)
- **Speakers:** Infinity Reference 4032 (4Ω, 4" coaxial) × 2
- **Audio path:** Pi → I2S → Amp Hat → Speakers

## Deployment

### Pi Deployment

The Pi runs `app.py` as a systemd service. Deploy from your dev PC with one command.

**systemd service file** (`system/fonie.service`):

```ini
[Unit]
Description=Fonie Music Player
After=network.target sound.target

[Service]
WorkingDirectory=/home/pi/fonie
ExecStart=/usr/bin/python3 app.py
Restart=always
RestartSec=5
User=pi
Environment=PYTHONUNBUFFERED=1

[Install]
WantedBy=multi-user.target
```

Install once on the Pi:

```bash
sudo cp ~/fonie/system/fonie.service /etc/systemd/system/
sudo systemctl daemon-reload
sudo systemctl enable fonie
sudo systemctl start fonie
```

**Deploy script** (`scripts/deploy-pi.sh`):

```bash
#!/bin/bash
set -e
PI_HOST="${1:-fonie.local}"

echo "🚀 Deploying Pi code to $PI_HOST..."
ssh $PI_HOST "cd ~/fonie && git pull && pip install -r requirements.txt --break-system-packages -q && sudo systemctl restart fonie"
echo "✅ Pi deployed and restarted"
```

Usage: `./scripts/deploy-pi.sh` or `./scripts/deploy-pi.sh 192.168.1.42`

### Pico Deployment (USB Bootloader)

Currently, the Pico firmware is flashed by connecting it directly to the development PC via USB and using the standard RP2040 USB bootloader (using `picotool`).

Build and upload from your dev PC:

```bash
cd firmware/pico && pio run -e pico -t upload
```

*(Note: An older plan involved using the Raspberry Pi as an SWD programmer via OpenOCD, but this was never implemented.)*

### Pico Deployment (future: UART OTA)

Since SWD debug pads on the RP2040 Zero are hard to access, a UART-based OTA update is planned. The Pi sends `{"event":"ENTER_OTA"}` over the existing UART connection (GP0/GP1). The Pico firmware enters a receive mode, accepts the new binary in chunks, writes to flash from a RAM-resident routine, and reboots. This avoids needing any physical access. Script: `scripts/pico_uart_flash.py` — not yet implemented.

### ESP32-C3 Deployment (WiFi OTA)

No extra wiring needed. Add ArduinoOTA to the ESP32 firmware, then flash from anywhere on the same network.

**Deploy script** (`scripts/deploy-esp32.sh`):

```bash
#!/bin/bash
set -e
ESP_HOST="${1:-fonie-esp32.local}"

echo "🔧 Building ESP32-C3 firmware..."
cd firmware/esp32 && pio run -e esp32c3_ota

echo "🚀 Uploading to ESP32-C3 via WiFi OTA..."
pio run -e esp32c3_ota -t upload
echo "✅ ESP32-C3 flashed"
```

### Full Deploy (all components)

For a complete system update from your dev PC:

```bash
./scripts/deploy-pi.sh        # Python app → restart service
./scripts/deploy-pico.sh      # Pico firmware → SWD flash
./scripts/deploy-esp32.sh     # ESP32 firmware → WiFi OTA
```

## What to Do

1. In the existing repo on the Pi, create the new directories: `firmware/pico/src/`, `firmware/esp32/src/`, `firmware/shared/`, `scripts/`, `system/`, `docs/`
2. Add the Pico `main.cpp` into `firmware/pico/src/main.cpp`
3. Add the ESP32-C3 `main.cpp` into `firmware/esp32/src/main.cpp`
4. Create the `platformio.ini` files for both MCU projects (see PlatformIO Configuration section)
5. Create `system/fonie.service` and the deploy scripts in `scripts/`
6. Create `firmware/shared/protocol.h` with event name constants
7. Copy `settings.json` to `settings.example.json` (committed template with defaults)
8. Move test scripts (`test*.py`) into a `tests/` directory
9. Add `.gitignore` for runtime data and build artifacts (see Repository Structure section)
10. Implement the three Pico firmware additions (strip pins GP4/GP5, Pololu OFF GP14, long-press shutdown)
11. Add ArduinoOTA handler to ESP32-C3 firmware

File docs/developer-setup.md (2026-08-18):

# Developer Setup Guide

This guide details how to set up a new development machine to work on the Fonie project, compile firmware, and deploy code to the Raspberry Pi, Pico, and ESP32-C3.

---

## 🛠️ Prerequisites

On your new development machine, ensure the following are installed:

1. **Python 3.9+** and pip.
2. **PlatformIO Core (CLI)**:
   - Used to compile and flash the microcontrollers.
   - Installation: `pip install platformio` or install the **PlatformIO IDE** extension in VS Code.
3. **SSH Client**:
   - Standard `ssh` and `scp` utilities must be available in your system path.

---

## 🔑 1. Setup SSH Authentication (Crucial)

To deploy or sync configurations, the deployment scripts rely on passwordless SSH/SCP authentication.

1. **Generate SSH Key** (if you don't already have one):
   ```bash
   ssh-keygen -t ed25519 -C "your_email@example.com"
   ```
2. **Copy the key to the Raspberry Pi**:
   ```bash
   ssh-copy-id allert@fonie.local
   ```
   *Replace `allert@fonie.local` with the Pi's actual hostname/IP if different.*
3. **Test connection**: Ensure you can SSH into the Pi without being prompted for a password:
   ```bash
   ssh allert@fonie.local
   ```

---

## 🔄 2. Sync Configuration Files

The active tag database, player volume/brightness settings, and Spotify credentials live on the running Pi. To download them to your local environment for backup, development, and reference:

- **Linux / macOS**:
  ```bash
  ./scripts/sync-from-pi.sh
  ```
- **Windows (PowerShell)**:
  ```powershell
  .\scripts\sync-from-pi.ps1
  ```

This will copy the following files (which are ignored in git) to your local repository root:
- `rfid_mappings.json` (Tag-to-music bindings)
- `settings.json` (Active volume/brightness)
- `.env` (Spotify API Credentials)

If you are setting up a fully offline developer workspace, you can manually copy `settings.example.json` to `settings.json` and set mock credentials in a `.env` file:
```env
SPOTIFY_CLIENT_ID=mock_id
SPOTIFY_CLIENT_SECRET=mock_secret
SPOTIFY_REDIRECT_URI=http://fonie.local/callback
```

---

## 🚀 3. Flashing & Deployment Workflow

Scripts are provided in the [scripts/](file:///c:/Users/aller/Projects/fonie/fonie/scripts) directory to build and deploy everything.

### A. Deploying Python Web App (Pi)
Copies the Flask code and templates to the Pi and restarts the systemd service.
- **Linux / macOS**: `./scripts/deploy-pi.sh [allert@fonie.local]`
- **Windows**: `.\scripts\deploy-pi.ps1 [-Target allert@fonie.local]`

### B. Deploying RP2040 Pico Firmware
Compiles the PlatformIO project under `firmware/pico`, transfers the binary to the Pi, and runs the UART flasher script on the Pi.
- **Linux / macOS**: `./scripts/deploy-pico.sh [allert@fonie.local]`
- **Windows**: `.\scripts\deploy-pico.ps1 [-Target allert@fonie.local]`

### C. Deploying ESP32-C3 Firmware
Compiles the PlatformIO project under `firmware/esp32` and uploads the firmware over Wi-Fi (ArduinoOTA).
- **Linux / macOS**: `./scripts/deploy-esp32.sh [fonie-esp32.local]`
- **Windows**: `.\scripts\deploy-esp32.ps1 [-Target fonie-esp32.local]`

---

## 📋 4. Verify Local Compilations

To verify that your compiler environment is correctly set up, run:
```bash
cd firmware/pico
pio run
cd ../esp32
pio run
```
PlatformIO will automatically download the required toolchains (Earle Philhower RP2040 core, ESP32 framework) and library dependencies (`Adafruit NeoPixel`, `ArduinoJson`).

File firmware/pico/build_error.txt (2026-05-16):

********************************************************************************
Obsolete PIO Core v6.1.15 is used (previous was 6.1.19)
Please remove multiple PIO Cores from a system:
https://docs.platformio.org/en/latest/core/installation/troubleshooting.html
********************************************************************************
Processing pico (platform: raspberrypi; board: pico; framework: arduino)
--------------------------------------------------------------------------------
Verbose mode can be enabled via `-v, --verbose` option
CONFIGURATION: https://docs.platformio.org/page/boards/raspberrypi/pico.html
PLATFORM: Raspberry Pi RP2040 (1.19.0) > Raspberry Pi Pico
HARDWARE: RP2040 133MHz, 264KB RAM, 2MB Flash
DEBUG: Current (cmsis-dap) External (cmsis-dap, jlink, raspberrypi-swd)
PACKAGES: 
 - framework-arduino-mbed @ 4.5.0 
 - tool-rp2040tools @ 1.0.2 
 - toolchain-gccarmnoneeabi @ 1.90201.191206 (9.2.1)
LDF: Library Dependency Finder -> https://bit.ly/configure-pio-ldf
LDF Modes: Finder ~ chain, Compatibility ~ soft
Found 43 compatible libraries
Scanning dependencies...
Dependency Graph
|-- Adafruit NeoPixel @ 1.15.5
|-- Wire
Building in release mode
Compiling .pio\build\pico\src\main.cpp.o
Compiling .pio\build\pico\liba62\Adafruit NeoPixel\Adafruit_Neopixel_RP2.cpp.o
Archiving .pio\build\pico\lib6d7\libWire.a
Archiving .pio\build\pico\libFrameworkArduinoVariant.a
Compiling .pio\build\pico\FrameworkArduino\WMath.cpp.o
Compiling .pio\build\pico\FrameworkArduino\abi.cpp.o
Compiling .pio\build\pico\FrameworkArduino\api\CanMsg.cpp.o
Compiling .pio\build\pico\FrameworkArduino\api\CanMsgRingbuffer.cpp.o
Compiling .pio\build\pico\FrameworkArduino\api\Common.cpp.o
Compiling .pio\build\pico\FrameworkArduino\api\IPAddress.cpp.o
Compiling .pio\build\pico\FrameworkArduino\api\PluggableUSB.cpp.o
Compiling .pio\build\pico\FrameworkArduino\api\Print.cpp.o
Compiling .pio\build\pico\FrameworkArduino\api\Stream.cpp.o
Compiling .pio\build\pico\FrameworkArduino\api\String.cpp.o
Compiling .pio\build\pico\FrameworkArduino\arm_hal_random.c.o
Compiling .pio\build\pico\FrameworkArduino\as_mbed_library\variant.cpp.o
Compiling .pio\build\pico\FrameworkArduino\itoa.c.o
Compiling .pio\build\pico\FrameworkArduino\main.cpp.o
Compiling .pio\build\pico\FrameworkArduino\mbed\platform\cxxsupport\mstd_mutex.cpp.o
Compiling .pio\build\pico\FrameworkArduino\pinToIndex.cpp.o
Compiling .pio\build\pico\FrameworkArduino\random_seed.cpp.o
Compiling .pio\build\pico\FrameworkArduino\timer.cpp.o
Compiling .pio\build\pico\FrameworkArduino\wiring.cpp.o
Compiling .pio\build\pico\FrameworkArduino\wiring_analog.cpp.o
Compiling .pio\build\pico\FrameworkArduino\wiring_digital.cpp.o
Compiling .pio\build\pico\FrameworkArduino\wiring_pulse.cpp.o
Compiling .pio\build\pico\FrameworkArduino\wiring_shift.cpp.o
pio : In file included from c:\users\aller\.platformio\packages\toolchain-gccarmnoneeabi@1.90201.191206\arm-none-eabi\i
nclude\c++\9.2.1\cassert:44,
At line:1 char:1
+ pio run -e pico > build_error.txt 2>&1
+ ~~~~~~~~~~~~~~~~~~~~~~~~~~~~~~~~~~~~~~
    + CategoryInfo          : NotSpecified: (In file include...2.1\cassert:44,:String) [], RemoteException
    + FullyQualifiedErrorId : NativeCommandError
 
                 from C:\Users\aller\.platformio\packages\framework-arduino-mbed\cores\arduino/mbed/targets/TARGET_RASP
BERRYPI/TARGET_RP2040/pico-sdk/common/pico_base/include/pico/assert.h:14,
                 from C:\Users\aller\.platformio\packages\framework-arduino-mbed\cores\arduino/mbed/targets/TARGET_RASP
BERRYPI/TARGET_RP2040/pico-sdk/common/pico_base/include/pico/types.h:12,
                 from C:\Users\aller\.platformio\packages\framework-arduino-mbed\cores\arduino/mbed/targets/TARGET_RASP
BERRYPI/TARGET_RP2040/pico-sdk/common/pico_base/include/pico.h:19,
                 from C:\Users\aller\.platformio\packages\framework-arduino-mbed\cores\arduino/mbed/targets/TARGET_RASP
BERRYPI/TARGET_RP2040/objects.h:30,
                 from C:\Users\aller\.platformio\packages\framework-arduino-mbed\cores\arduino/mbed/targets/TARGET_RASP
BERRYPI/TARGET_RP2040/device.h:35,
                 from C:\Users\aller\.platformio\packages\framework-arduino-mbed\cores\arduino/mbed/platform/include/pl
atform/platform.h:28,
                 from C:\Users\aller\.platformio\packages\framework-arduino-mbed\cores\arduino/mbed/platform/include/pl
atform/FileHandle.h:25,
                 from C:\Users\aller\.platformio\packages\framework-arduino-mbed\cores\arduino/macros.h:41,
                 from C:\Users\aller\.platformio\packages\framework-arduino-mbed\variants\RASPBERRY_PI_PICO/pins_arduin
o.h:2,
                 from C:\Users\aller\.platformio\packages\framework-arduino-mbed\cores\arduino/Arduino.h:76,
                 from .pio\libdeps\pico\Adafruit NeoPixel\Adafruit_NeoPixel.h:40,
                 from .pio\libdeps\pico\Adafruit NeoPixel\Adafruit_Neopixel_RP2.cpp:3:
C:\Users\aller\.platformio\packages\framework-arduino-mbed\cores\arduino/mbed/targets/TARGET_RASPBERRYPI/TARGET_RP2040/
pico-sdk/rp2_common/hardware_pio/include/hardware/pio.h: In function 'void check_pio_param(PIO)':
C:\Users\aller\.platformio\packages\framework-arduino-mbed\cores\arduino/mbed/targets/TARGET_RASPBERRYPI/TARGET_RP2040/
pico-sdk/rp2040/hardware_regs/include/hardware/regs/addressmap.h:68:22: warning: type qualifiers ignored on cast result
 type [-Wignored-qualifiers]
   68 | #define PIO0_BASE _u(0x50200000)
      |                      ^~~~~~~~~~
C:\Users\aller\.platformio\packages\framework-arduino-mbed\cores\arduino/mbed/targets/TARGET_RASPBERRYPI/TARGET_RP2040/
pico-sdk/rp2_common/hardware_pio/include/hardware/pio.h:120:5: note: in expansion of macro 'valid_params_if'
  120 |     valid_params_if(PIO, pio == pio0 || pio == pio1);
      |     ^~~~~~~~~~~~~~~
C:\Users\aller\.platformio\packages\framework-arduino-mbed\cores\arduino/mbed/targets/TARGET_RASPBERRYPI/TARGET_RP2040/
pico-sdk/rp2040/hardware_regs/include/hardware/regs/addressmap.h:68:19: note: in expansion of macro '_u'
   68 | #define PIO0_BASE _u(0x50200000)
      |                   ^~
C:\Users\aller\.platformio\packages\framework-arduino-mbed\cores\arduino/mbed/targets/TARGET_RASPBERRYPI/TARGET_RP2040/
pico-sdk/rp2040/hardware_structs/include/hardware/structs/pio.h:278:35: note: in expansion of macro 'PIO0_BASE'
  278 | #define pio0_hw ((pio_hw_t *const)PIO0_BASE)
      |                                   ^~~~~~~~~
C:\Users\aller\.platformio\packages\framework-arduino-mbed\cores\arduino/mbed/targets/TARGET_RASPBERRYPI/TARGET_RP2040/
pico-sdk/rp2_common/hardware_pio/include/hardware/pio.h:78:14: note: in expansion of macro 'pio0_hw'
   78 | #define pio0 pio0_hw
      |              ^~~~~~~
C:\Users\aller\.platformio\packages\framework-arduino-mbed\cores\arduino/mbed/targets/TARGET_RASPBERRYPI/TARGET_RP2040/
pico-sdk/rp2_common/hardware_pio/include/hardware/pio.h:120:33: note: in expansion of macro 'pio0'
  120 |     valid_params_if(PIO, pio == pio0 || pio == pio1);
      |                                 ^~~~
C:\Users\aller\.platformio\packages\framework-arduino-mbed\cores\arduino/mbed/targets/TARGET_RASPBERRYPI/TARGET_RP2040/
pico-sdk/rp2040/hardware_regs/include/hardware/regs/addressmap.h:69:22: warning: type qualifiers ignored on cast result
 type [-Wignored-qualifiers]
   69 | #define PIO1_BASE _u(0x50300000)
      |                      ^~~~~~~~~~
C:\Users\aller\.platformio\packages\framework-arduino-mbed\cores\arduino/mbed/targets/TARGET_RASPBERRYPI/TARGET_RP2040/
pico-sdk/rp2_common/hardware_pio/include/hardware/pio.h:120:5: note: in expansion of macro 'valid_params_if'
  120 |     valid_params_if(PIO, pio == pio0 || pio == pio1);
      |     ^~~~~~~~~~~~~~~
C:\Users\aller\.platformio\packages\framework-arduino-mbed\cores\arduino/mbed/targets/TARGET_RASPBERRYPI/TARGET_RP2040/
pico-sdk/rp2040/hardware_regs/include/hardware/regs/addressmap.h:69:19: note: in expansion of macro '_u'
   69 | #define PIO1_BASE _u(0x50300000)
      |                   ^~
C:\Users\aller\.platformio\packages\framework-arduino-mbed\cores\arduino/mbed/targets/TARGET_RASPBERRYPI/TARGET_RP2040/
pico-sdk/rp2040/hardware_structs/include/hardware/structs/pio.h:279:35: note: in expansion of macro 'PIO1_BASE'
  279 | #define pio1_hw ((pio_hw_t *const)PIO1_BASE)
      |                                   ^~~~~~~~~
C:\Users\aller\.platformio\packages\framework-arduino-mbed\cores\arduino/mbed/targets/TARGET_RASPBERRYPI/TARGET_RP2040/
pico-sdk/rp2_common/hardware_pio/include/hardware/pio.h:88:14: note: in expansion of macro 'pio1_hw'
   88 | #define pio1 pio1_hw
      |              ^~~~~~~
C:\Users\aller\.platformio\packages\framework-arduino-mbed\cores\arduino/mbed/targets/TARGET_RASPBERRYPI/TARGET_RP2040/
pico-sdk/rp2_common/hardware_pio/include/hardware/pio.h:120:48: note: in expansion of macro 'pio1'
  120 |     valid_params_if(PIO, pio == pio0 || pio == pio1);
      |                                                ^~~~
In file included from C:\Users\aller\.platformio\packages\framework-arduino-mbed\cores\arduino/mbed/targets/TARGET_RASP
BERRYPI/TARGET_RP2040/pico-sdk/rp2_common/pico_platform/include/pico/platform.h:19,
                 from C:\Users\aller\.platformio\packages\framework-arduino-mbed\cores\arduino/mbed/targets/TARGET_RASP
BERRYPI/TARGET_RP2040/pico-sdk/common/pico_base/include/pico.h:22,
                 from C:\Users\aller\.platformio\packages\framework-arduino-mbed\cores\arduino/mbed/targets/TARGET_RASP
BERRYPI/TARGET_RP2040/objects.h:30,
                 from C:\Users\aller\.platformio\packages\framework-arduino-mbed\cores\arduino/mbed/targets/TARGET_RASP
BERRYPI/TARGET_RP2040/device.h:35,
                 from C:\Users\aller\.platformio\packages\framework-arduino-mbed\cores\arduino/mbed/platform/include/pl
atform/platform.h:28,
                 from C:\Users\aller\.platformio\packages\framework-arduino-mbed\cores\arduino/mbed/platform/include/pl
atform/FileHandle.h:25,
                 from C:\Users\aller\.platformio\packages\framework-arduino-mbed\cores\arduino/macros.h:41,
                 from C:\Users\aller\.platformio\packages\framework-arduino-mbed\variants\RASPBERRY_PI_PICO/pins_arduin
o.h:2,
                 from C:\Users\aller\.platformio\packages\framework-arduino-mbed\cores\arduino/Arduino.h:76,
                 from .pio\libdeps\pico\Adafruit NeoPixel\Adafruit_NeoPixel.h:40,
                 from .pio\libdeps\pico\Adafruit NeoPixel\Adafruit_Neopixel_RP2.cpp:3:
C:\Users\aller\.platformio\packages\framework-arduino-mbed\cores\arduino/mbed/targets/TARGET_RASPBERRYPI/TARGET_RP2040/
pico-sdk/rp2_common/hardware_pio/include/hardware/pio.h: In function 'uint pio_get_index(PIO)':
C:\Users\aller\.platformio\packages\framework-arduino-mbed\cores\arduino/mbed/targets/TARGET_RASPBERRYPI/TARGET_RP2040/
pico-sdk/rp2040/hardware_regs/include/hardware/regs/addressmap.h:69:22: warning: type qualifiers ignored on cast result
 type [-Wignored-qualifiers]
   69 | #define PIO1_BASE _u(0x50300000)
      |                      ^~~~~~~~~~
C:\Users\aller\.platformio\packages\framework-arduino-mbed\cores\arduino/mbed/targets/TARGET_RASPBERRYPI/TARGET_RP2040/
pico-sdk/rp2040/hardware_regs/include/hardware/platform_defs.h:16:15: note: in definition of macro '_u'
   16 | #define _u(x) x ## u
      |               ^
C:\Users\aller\.platformio\packages\framework-arduino-mbed\cores\arduino/mbed/targets/TARGET_RASPBERRYPI/TARGET_RP2040/
pico-sdk/rp2040/hardware_structs/include/hardware/structs/pio.h:279:35: note: in expansion of macro 'PIO1_BASE'
  279 | #define pio1_hw ((pio_hw_t *const)PIO1_BASE)
      |                                   ^~~~~~~~~
C:\Users\aller\.platformio\packages\framework-arduino-mbed\cores\arduino/mbed/targets/TARGET_RASPBERRYPI/TARGET_RP2040/
pico-sdk/rp2_common/hardware_pio/include/hardware/pio.h:88:14: note: in expansion of macro 'pio1_hw'
   88 | #define pio1 pio1_hw
      |              ^~~~~~~
C:\Users\aller\.platformio\packages\framework-arduino-mbed\cores\arduino/mbed/targets/TARGET_RASPBERRYPI/TARGET_RP2040/
pico-sdk/rp2_common/hardware_pio/include/hardware/pio.h:418:19: note: in expansion of macro 'pio1'
  418 |     return pio == pio1 ? 1 : 0;
      |                   ^~~~
C:\Users\aller\.platformio\packages\framework-arduino-mbed\cores\arduino/mbed/targets/TARGET_RASPBERRYPI/TARGET_RP2040/
pico-sdk/rp2_common/hardware_pio/include/hardware/pio.h: In function 'void pio_gpio_init(PIO, uint)':
C:\Users\aller\.platformio\packages\framework-arduino-mbed\cores\arduino/mbed/targets/TARGET_RASPBERRYPI/TARGET_RP2040/
pico-sdk/rp2040/hardware_regs/include/hardware/regs/addressmap.h:68:22: warning: type qualifiers ignored on cast result
 type [-Wignored-qualifiers]
   68 | #define PIO0_BASE _u(0x50200000)
      |                      ^~~~~~~~~~
C:\Users\aller\.platformio\packages\framework-arduino-mbed\cores\arduino/mbed/targets/TARGET_RASPBERRYPI/TARGET_RP2040/
pico-sdk/rp2040/hardware_regs/include/hardware/platform_defs.h:16:15: note: in definition of macro '_u'
   16 | #define _u(x) x ## u
      |               ^
C:\Users\aller\.platformio\packages\framework-arduino-mbed\cores\arduino/mbed/targets/TARGET_RASPBERRYPI/TARGET_RP2040/
pico-sdk/rp2040/hardware_structs/include/hardware/structs/pio.h:278:35: note: in expansion of macro 'PIO0_BASE'
  278 | #define pio0_hw ((pio_hw_t *const)PIO0_BASE)
      |                                   ^~~~~~~~~
C:\Users\aller\.platformio\packages\framework-arduino-mbed\cores\arduino/mbed/targets/TARGET_RASPBERRYPI/TARGET_RP2040/
pico-sdk/rp2_common/hardware_pio/include/hardware/pio.h:78:14: note: in expansion of macro 'pio0_hw'
   78 | #define pio0 pio0_hw
      |              ^~~~~~~
C:\Users\aller\.platformio\packages\framework-arduino-mbed\cores\arduino/mbed/targets/TARGET_RASPBERRYPI/TARGET_RP2040/
pico-sdk/rp2_common/hardware_pio/include/hardware/pio.h:436:35: note: in expansion of macro 'pio0'
  436 |     gpio_set_function(pin, pio == pio0 ? GPIO_FUNC_PIO0 : GPIO_FUNC_PIO1);
      |                                   ^~~~
C:\Users\aller\.platformio\packages\framework-arduino-mbed\cores\arduino/mbed/targets/TARGET_RASPBERRYPI/TARGET_RP2040/
pico-sdk/rp2_common/hardware_pio/include/hardware/pio.h: In function 'uint pio_get_dreq(PIO, uint, bool)':
C:\Users\aller\.platformio\packages\framework-arduino-mbed\cores\arduino/mbed/targets/TARGET_RASPBERRYPI/TARGET_RP2040/
pico-sdk/rp2040/hardware_regs/include/hardware/regs/addressmap.h:68:22: warning: type qualifiers ignored on cast result
 type [-Wignored-qualifiers]
   68 | #define PIO0_BASE _u(0x50200000)
      |                      ^~~~~~~~~~
C:\Users\aller\.platformio\packages\framework-arduino-mbed\cores\arduino/mbed/targets/TARGET_RASPBERRYPI/TARGET_RP2040/
pico-sdk/rp2040/hardware_regs/include/hardware/platform_defs.h:16:15: note: in definition of macro '_u'
   16 | #define _u(x) x ## u
      |               ^
C:\Users\aller\.platformio\packages\framework-arduino-mbed\cores\arduino/mbed/targets/TARGET_RASPBERRYPI/TARGET_RP2040/
pico-sdk/rp2040/hardware_structs/include/hardware/structs/pio.h:278:35: note: in expansion of macro 'PIO0_BASE'
  278 | #define pio0_hw ((pio_hw_t *const)PIO0_BASE)
      |                                   ^~~~~~~~~
C:\Users\aller\.platformio\packages\framework-arduino-mbed\cores\arduino/mbed/targets/TARGET_RASPBERRYPI/TARGET_RP2040/
pico-sdk/rp2_common/hardware_pio/include/hardware/pio.h:78:14: note: in expansion of macro 'pio0_hw'
   78 | #define pio0 pio0_hw
      |              ^~~~~~~
C:\Users\aller\.platformio\packages\framework-arduino-mbed\cores\arduino/mbed/targets/TARGET_RASPBERRYPI/TARGET_RP2040/
pico-sdk/rp2_common/hardware_pio/include/hardware/pio.h:454:64: note: in expansion of macro 'pio0'
  454 |     return sm + (is_tx ? 0 : NUM_PIO_STATE_MACHINES) + (pio == pio0 ? DREQ_PIO0_TX0 : DREQ_PIO1_TX0);
      |                                                                ^~~~
.pio\libdeps\pico\Adafruit NeoPixel\Adafruit_Neopixel_RP2.cpp: In member function 'bool Adafruit_NeoPixel::rp2040claimP
IO()':
.pio\libdeps\pico\Adafruit NeoPixel\Adafruit_Neopixel_RP2.cpp:9:9: error: 'pio_claim_free_sm_and_add_program_for_gpio_r
ange' was not declared in this scope
    9 |   if (! pio_claim_free_sm_and_add_program_for_gpio_range(&ws2812_program,
      |         ^~~~~~~~~~~~~~~~~~~~~~~~~~~~~~~~~~~~~~~~~~~~~~~~
.pio\libdeps\pico\Adafruit NeoPixel\Adafruit_Neopixel_RP2.cpp: In member function 'void Adafruit_NeoPixel::rp2040releas
ePIO()':
.pio\libdeps\pico\Adafruit NeoPixel\Adafruit_Neopixel_RP2.cpp:35:3: error: 'pio_remove_program_and_unclaim_sm' was not 
declared in this scope
   35 |   pio_remove_program_and_unclaim_sm(&ws2812_program, pio, pio_sm,  pio_program_offset);
      |   ^~~~~~~~~~~~~~~~~~~~~~~~~~~~~~~~~
.pio\libdeps\pico\Adafruit NeoPixel\Adafruit_Neopixel_RP2.cpp: In member function 'void Adafruit_NeoPixel::rp2040Show(u
int8_t*, uint32_t)':
.pio\libdeps\pico\Adafruit NeoPixel\Adafruit_Neopixel_RP2.cpp:43:24: warning: comparison of unsigned expression < 0 is 
always false [-Wtype-limits]
   43 |   if (! pio || (pio_sm < 0)) {
      |                 ~~~~~~~^~~
In file included from c:\users\aller\.platformio\packages\toolchain-gccarmnoneeabi@1.90201.191206\arm-none-eabi\include
\c++\9.2.1\cassert:44,
                 from C:\Users\aller\.platformio\packages\framework-arduino-mbed\cores\arduino/mbed/targets/TARGET_RASP
BERRYPI/TARGET_RP2040/pico-sdk/common/pico_base/include/pico/assert.h:14,
                 from C:\Users\aller\.platformio\packages\framework-arduino-mbed\cores\arduino/mbed/targets/TARGET_RASP
BERRYPI/TARGET_RP2040/pico-sdk/common/pico_base/include/pico/types.h:12,
                 from C:\Users\aller\.platformio\packages\framework-arduino-mbed\cores\arduino/mbed/targets/TARGET_RASP
BERRYPI/TARGET_RP2040/pico-sdk/common/pico_base/include/pico.h:19,
                 from C:\Users\aller\.platformio\packages\framework-arduino-mbed\cores\arduino/mbed/targets/TARGET_RASP
BERRYPI/TARGET_RP2040/objects.h:30,
                 from C:\Users\aller\.platformio\packages\framework-arduino-mbed\cores\arduino/mbed/targets/TARGET_RASP
BERRYPI/TARGET_RP2040/device.h:35,
                 from C:\Users\aller\.platformio\packages\framework-arduino-mbed\cores\arduino/mbed/platform/include/pl
atform/platform.h:28,
                 from C:\Users\aller\.platformio\packages\framework-arduino-mbed\cores\arduino/mbed/platform/include/pl
atform/FileHandle.h:25,
                 from C:\Users\aller\.platformio\packages\framework-arduino-mbed\cores\arduino/macros.h:41,
                 from C:\Users\aller\.platformio\packages\framework-arduino-mbed\variants\RASPBERRY_PI_PICO/pins_arduin
o.h:2,
                 from C:\Users\aller\.platformio\packages\framework-arduino-mbed\cores\arduino/Arduino.h:76,
                 from .pio\libdeps\pico\Adafruit NeoPixel/Adafruit_NeoPixel.h:40,
                 from src\main.cpp:1:
C:\Users\aller\.platformio\packages\framework-arduino-mbed\cores\arduino/mbed/targets/TARGET_RASPBERRYPI/TARGET_RP2040/
pico-sdk/rp2_common/hardware_pio/include/hardware/pio.h: In function 'void check_pio_param(PIO)':
C:\Users\aller\.platformio\packages\framework-arduino-mbed\cores\arduino/mbed/targets/TARGET_RASPBERRYPI/TARGET_RP2040/
pico-sdk/rp2040/hardware_regs/include/hardware/regs/addressmap.h:68:22: warning: type qualifiers ignored on cast result
 type [-Wignored-qualifiers]
   68 | #define PIO0_BASE _u(0x50200000)
      |                      ^~~~~~~~~~
C:\Users\aller\.platformio\packages\framework-arduino-mbed\cores\arduino/mbed/targets/TARGET_RASPBERRYPI/TARGET_RP2040/
pico-sdk/rp2_common/hardware_pio/include/hardware/pio.h:120:5: note: in expansion of macro 'valid_params_if'
  120 |     valid_params_if(PIO, pio == pio0 || pio == pio1);
      |     ^~~~~~~~~~~~~~~
C:\Users\aller\.platformio\packages\framework-arduino-mbed\cores\arduino/mbed/targets/TARGET_RASPBERRYPI/TARGET_RP2040/
pico-sdk/rp2040/hardware_regs/include/hardware/regs/addressmap.h:68:19: note: in expansion of macro '_u'
   68 | #define PIO0_BASE _u(0x50200000)
      |                   ^~
C:\Users\aller\.platformio\packages\framework-arduino-mbed\cores\arduino/mbed/targets/TARGET_RASPBERRYPI/TARGET_RP2040/
pico-sdk/rp2040/hardware_structs/include/hardware/structs/pio.h:278:35: note: in expansion of macro 'PIO0_BASE'
  278 | #define pio0_hw ((pio_hw_t *const)PIO0_BASE)
      |                                   ^~~~~~~~~
C:\Users\aller\.platformio\packages\framework-arduino-mbed\cores\arduino/mbed/targets/TARGET_RASPBERRYPI/TARGET_RP2040/
pico-sdk/rp2_common/hardware_pio/include/hardware/pio.h:78:14: note: in expansion of macro 'pio0_hw'
   78 | #define pio0 pio0_hw
      |              ^~~~~~~
C:\Users\aller\.platformio\packages\framework-arduino-mbed\cores\arduino/mbed/targets/TARGET_RASPBERRYPI/TARGET_RP2040/
pico-sdk/rp2_common/hardware_pio/include/hardware/pio.h:120:33: note: in expansion of macro 'pio0'
  120 |     valid_params_if(PIO, pio == pio0 || pio == pio1);
      |                                 ^~~~
C:\Users\aller\.platformio\packages\framework-arduino-mbed\cores\arduino/mbed/targets/TARGET_RASPBERRYPI/TARGET_RP2040/
pico-sdk/rp2040/hardware_regs/include/hardware/regs/addressmap.h:69:22: warning: type qualifiers ignored on cast result
 type [-Wignored-qualifiers]
   69 | #define PIO1_BASE _u(0x50300000)
      |                      ^~~~~~~~~~
C:\Users\aller\.platformio\packages\framework-arduino-mbed\cores\arduino/mbed/targets/TARGET_RASPBERRYPI/TARGET_RP2040/
pico-sdk/rp2_common/hardware_pio/include/hardware/pio.h:120:5: note: in expansion of macro 'valid_params_if'
  120 |     valid_params_if(PIO, pio == pio0 || pio == pio1);
      |     ^~~~~~~~~~~~~~~
C:\Users\aller\.platformio\packages\framework-arduino-mbed\cores\arduino/mbed/targets/TARGET_RASPBERRYPI/TARGET_RP2040/
pico-sdk/rp2040/hardware_regs/include/hardware/regs/addressmap.h:69:19: note: in expansion of macro '_u'
   69 | #define PIO1_BASE _u(0x50300000)
      |                   ^~
C:\Users\aller\.platformio\packages\framework-arduino-mbed\cores\arduino/mbed/targets/TARGET_RASPBERRYPI/TARGET_RP2040/
pico-sdk/rp2040/hardware_structs/include/hardware/structs/pio.h:279:35: note: in expansion of macro 'PIO1_BASE'
  279 | #define pio1_hw ((pio_hw_t *const)PIO1_BASE)
      |                                   ^~~~~~~~~
C:\Users\aller\.platformio\packages\framework-arduino-mbed\cores\arduino/mbed/targets/TARGET_RASPBERRYPI/TARGET_RP2040/
pico-sdk/rp2_common/hardware_pio/include/hardware/pio.h:88:14: note: in expansion of macro 'pio1_hw'
   88 | #define pio1 pio1_hw
      |              ^~~~~~~
C:\Users\aller\.platformio\packages\framework-arduino-mbed\cores\arduino/mbed/targets/TARGET_RASPBERRYPI/TARGET_RP2040/
pico-sdk/rp2_common/hardware_pio/include/hardware/pio.h:120:48: note: in expansion of macro 'pio1'
  120 |     valid_params_if(PIO, pio == pio0 || pio == pio1);
      |                                                ^~~~
In file included from C:\Users\aller\.platformio\packages\framework-arduino-mbed\cores\arduino/mbed/targets/TARGET_RASP
BERRYPI/TARGET_RP2040/pico-sdk/rp2_common/pico_platform/include/pico/platform.h:19,
                 from C:\Users\aller\.platformio\packages\framework-arduino-mbed\cores\arduino/mbed/targets/TARGET_RASP
BERRYPI/TARGET_RP2040/pico-sdk/common/pico_base/include/pico.h:22,
                 from C:\Users\aller\.platformio\packages\framework-arduino-mbed\cores\arduino/mbed/targets/TARGET_RASP
BERRYPI/TARGET_RP2040/objects.h:30,
                 from C:\Users\aller\.platformio\packages\framework-arduino-mbed\cores\arduino/mbed/targets/TARGET_RASP
BERRYPI/TARGET_RP2040/device.h:35,
                 from C:\Users\aller\.platformio\packages\framework-arduino-mbed\cores\arduino/mbed/platform/include/pl
atform/platform.h:28,
                 from C:\Users\aller\.platformio\packages\framework-arduino-mbed\cores\arduino/mbed/platform/include/pl
atform/FileHandle.h:25,
                 from C:\Users\aller\.platformio\packages\framework-arduino-mbed\cores\arduino/macros.h:41,
                 from C:\Users\aller\.platformio\packages\framework-arduino-mbed\variants\RASPBERRY_PI_PICO/pins_arduin
o.h:2,
                 from C:\Users\aller\.platformio\packages\framework-arduino-mbed\cores\arduino/Arduino.h:76,
                 from .pio\libdeps\pico\Adafruit NeoPixel/Adafruit_NeoPixel.h:40,
                 from src\main.cpp:1:
C:\Users\aller\.platformio\packages\framework-arduino-mbed\cores\arduino/mbed/targets/TARGET_RASPBERRYPI/TARGET_RP2040/
pico-sdk/rp2_common/hardware_pio/include/hardware/pio.h: In function 'uint pio_get_index(PIO)':
C:\Users\aller\.platformio\packages\framework-arduino-mbed\cores\arduino/mbed/targets/TARGET_RASPBERRYPI/TARGET_RP2040/
pico-sdk/rp2040/hardware_regs/include/hardware/regs/addressmap.h:69:22: warning: type qualifiers ignored on cast result
 type [-Wignored-qualifiers]
   69 | #define PIO1_BASE _u(0x50300000)
      |                      ^~~~~~~~~~
C:\Users\aller\.platformio\packages\framework-arduino-mbed\cores\arduino/mbed/targets/TARGET_RASPBERRYPI/TARGET_RP2040/
pico-sdk/rp2040/hardware_regs/include/hardware/platform_defs.h:16:15: note: in definition of macro '_u'
   16 | #define _u(x) x ## u
      |               ^
C:\Users\aller\.platformio\packages\framework-arduino-mbed\cores\arduino/mbed/targets/TARGET_RASPBERRYPI/TARGET_RP2040/
pico-sdk/rp2040/hardware_structs/include/hardware/structs/pio.h:279:35: note: in expansion of macro 'PIO1_BASE'
  279 | #define pio1_hw ((pio_hw_t *const)PIO1_BASE)
      |                                   ^~~~~~~~~
C:\Users\aller\.platformio\packages\framework-arduino-mbed\cores\arduino/mbed/targets/TARGET_RASPBERRYPI/TARGET_RP2040/
pico-sdk/rp2_common/hardware_pio/include/hardware/pio.h:88:14: note: in expansion of macro 'pio1_hw'
   88 | #define pio1 pio1_hw
      |              ^~~~~~~
C:\Users\aller\.platformio\packages\framework-arduino-mbed\cores\arduino/mbed/targets/TARGET_RASPBERRYPI/TARGET_RP2040/
pico-sdk/rp2_common/hardware_pio/include/hardware/pio.h:418:19: note: in expansion of macro 'pio1'
  418 |     return pio == pio1 ? 1 : 0;
      |                   ^~~~
C:\Users\aller\.platformio\packages\framework-arduino-mbed\cores\arduino/mbed/targets/TARGET_RASPBERRYPI/TARGET_RP2040/
pico-sdk/rp2_common/hardware_pio/include/hardware/pio.h: In function 'void pio_gpio_init(PIO, uint)':
C:\Users\aller\.platformio\packages\framework-arduino-mbed\cores\arduino/mbed/targets/TARGET_RASPBERRYPI/TARGET_RP2040/
pico-sdk/rp2040/hardware_regs/include/hardware/regs/addressmap.h:68:22: warning: type qualifiers ignored on cast result
 type [-Wignored-qualifiers]
   68 | #define PIO0_BASE _u(0x50200000)
      |                      ^~~~~~~~~~
C:\Users\aller\.platformio\packages\framework-arduino-mbed\cores\arduino/mbed/targets/TARGET_RASPBERRYPI/TARGET_RP2040/
pico-sdk/rp2040/hardware_regs/include/hardware/platform_defs.h:16:15: note: in definition of macro '_u'
   16 | #define _u(x) x ## u
      |               ^
C:\Users\aller\.platformio\packages\framework-arduino-mbed\cores\arduino/mbed/targets/TARGET_RASPBERRYPI/TARGET_RP2040/
pico-sdk/rp2040/hardware_structs/include/hardware/structs/pio.h:278:35: note: in expansion of macro 'PIO0_BASE'
  278 | #define pio0_hw ((pio_hw_t *const)PIO0_BASE)
      |                                   ^~~~~~~~~
C:\Users\aller\.platformio\packages\framework-arduino-mbed\cores\arduino/mbed/targets/TARGET_RASPBERRYPI/TARGET_RP2040/
pico-sdk/rp2_common/hardware_pio/include/hardware/pio.h:78:14: note: in expansion of macro 'pio0_hw'
   78 | #define pio0 pio0_hw
      |              ^~~~~~~
C:\Users\aller\.platformio\packages\framework-arduino-mbed\cores\arduino/mbed/targets/TARGET_RASPBERRYPI/TARGET_RP2040/
pico-sdk/rp2_common/hardware_pio/include/hardware/pio.h:436:35: note: in expansion of macro 'pio0'
  436 |     gpio_set_function(pin, pio == pio0 ? GPIO_FUNC_PIO0 : GPIO_FUNC_PIO1);
      |                                   ^~~~
C:\Users\aller\.platformio\packages\framework-arduino-mbed\cores\arduino/mbed/targets/TARGET_RASPBERRYPI/TARGET_RP2040/
pico-sdk/rp2_common/hardware_pio/include/hardware/pio.h: In function 'uint pio_get_dreq(PIO, uint, bool)':
C:\Users\aller\.platformio\packages\framework-arduino-mbed\cores\arduino/mbed/targets/TARGET_RASPBERRYPI/TARGET_RP2040/
pico-sdk/rp2040/hardware_regs/include/hardware/regs/addressmap.h:68:22: warning: type qualifiers ignored on cast result
 type [-Wignored-qualifiers]
   68 | #define PIO0_BASE _u(0x50200000)
      |                      ^~~~~~~~~~
C:\Users\aller\.platformio\packages\framework-arduino-mbed\cores\arduino/mbed/targets/TARGET_RASPBERRYPI/TARGET_RP2040/
pico-sdk/rp2040/hardware_regs/include/hardware/platform_defs.h:16:15: note: in definition of macro '_u'
   16 | #define _u(x) x ## u
      |               ^
C:\Users\aller\.platformio\packages\framework-arduino-mbed\cores\arduino/mbed/targets/TARGET_RASPBERRYPI/TARGET_RP2040/
pico-sdk/rp2040/hardware_structs/include/hardware/structs/pio.h:278:35: note: in expansion of macro 'PIO0_BASE'
  278 | #define pio0_hw ((pio_hw_t *const)PIO0_BASE)
      |                                   ^~~~~~~~~
C:\Users\aller\.platformio\packages\framework-arduino-mbed\cores\arduino/mbed/targets/TARGET_RASPBERRYPI/TARGET_RP2040/
pico-sdk/rp2_common/hardware_pio/include/hardware/pio.h:78:14: note: in expansion of macro 'pio0_hw'
   78 | #define pio0 pio0_hw
      |              ^~~~~~~
C:\Users\aller\.platformio\packages\framework-arduino-mbed\cores\arduino/mbed/targets/TARGET_RASPBERRYPI/TARGET_RP2040/
pico-sdk/rp2_common/hardware_pio/include/hardware/pio.h:454:64: note: in expansion of macro 'pio0'
  454 |     return sm + (is_tx ? 0 : NUM_PIO_STATE_MACHINES) + (pio == pio0 ? DREQ_PIO0_TX0 : DREQ_PIO1_TX0);
      |                                                                ^~~~
*** [.pio\build\pico\liba62\Adafruit NeoPixel\Adafruit_Neopixel_RP2.cpp.o] Error 1
src\main.cpp: In function 'void ina226_writeReg(uint8_t, uint16_t)':
src\main.cpp:105:3: error: 'Wire1' was not declared in this scope; did you mean 'Wire'?
  105 |   Wire1.beginTransmission(INA226_ADDR);
      |   ^~~~~
      |   Wire
src\main.cpp: In function 'uint16_t ina226_readReg(uint8_t)':
src\main.cpp:113:3: error: 'Wire1' was not declared in this scope; did you mean 'Wire'?
  113 |   Wire1.beginTransmission(INA226_ADDR);
      |   ^~~~~
      |   Wire
src\main.cpp: In function 'void ina226_init()':
src\main.cpp:123:3: error: 'Wire1' was not declared in this scope; did you mean 'Wire'?
  123 |   Wire1.setSDA(INA226_SDA);
      |   ^~~~~
      |   Wire
src\main.cpp: In function 'bool ina226_scan()':
src\main.cpp:140:3: error: 'Wire1' was not declared in this scope; did you mean 'Wire'?
  140 |   Wire1.beginTransmission(INA226_ADDR);
      |   ^~~~~
      |   Wire
src\main.cpp: In function 'void updateSoC()':
src\main.cpp:204:5: error: 'reportSoC' was not declared in this scope
  204 |     reportSoC();
      |     ^~~~~~~~~
src\main.cpp:243:5: error: 'reportSoC' was not declared in this scope
  243 |     reportSoC();
      |     ^~~~~~~~~
src\main.cpp: In function 'void setup()':
src\main.cpp:654:11: error: 'class arduino::UART' has no member named 'setTX'
  654 |   Serial1.setTX(0); Serial1.setRX(1); Serial1.begin(115200);
      |           ^~~~~
src\main.cpp:654:29: error: 'class arduino::UART' has no member named 'setRX'
  654 |   Serial1.setTX(0); Serial1.setRX(1); Serial1.begin(115200);
      |                             ^~~~~
*** [.pio\build\pico\src\main.cpp.o] Error 1
========================== [FAILED] Took 5.65 seconds ==========================

Environment    Status    Duration
-------------  --------  ------------
pico           FAILED    00:00:05.655
==================== 1 failed, 0 succeeded in 00:00:05.655 ====================

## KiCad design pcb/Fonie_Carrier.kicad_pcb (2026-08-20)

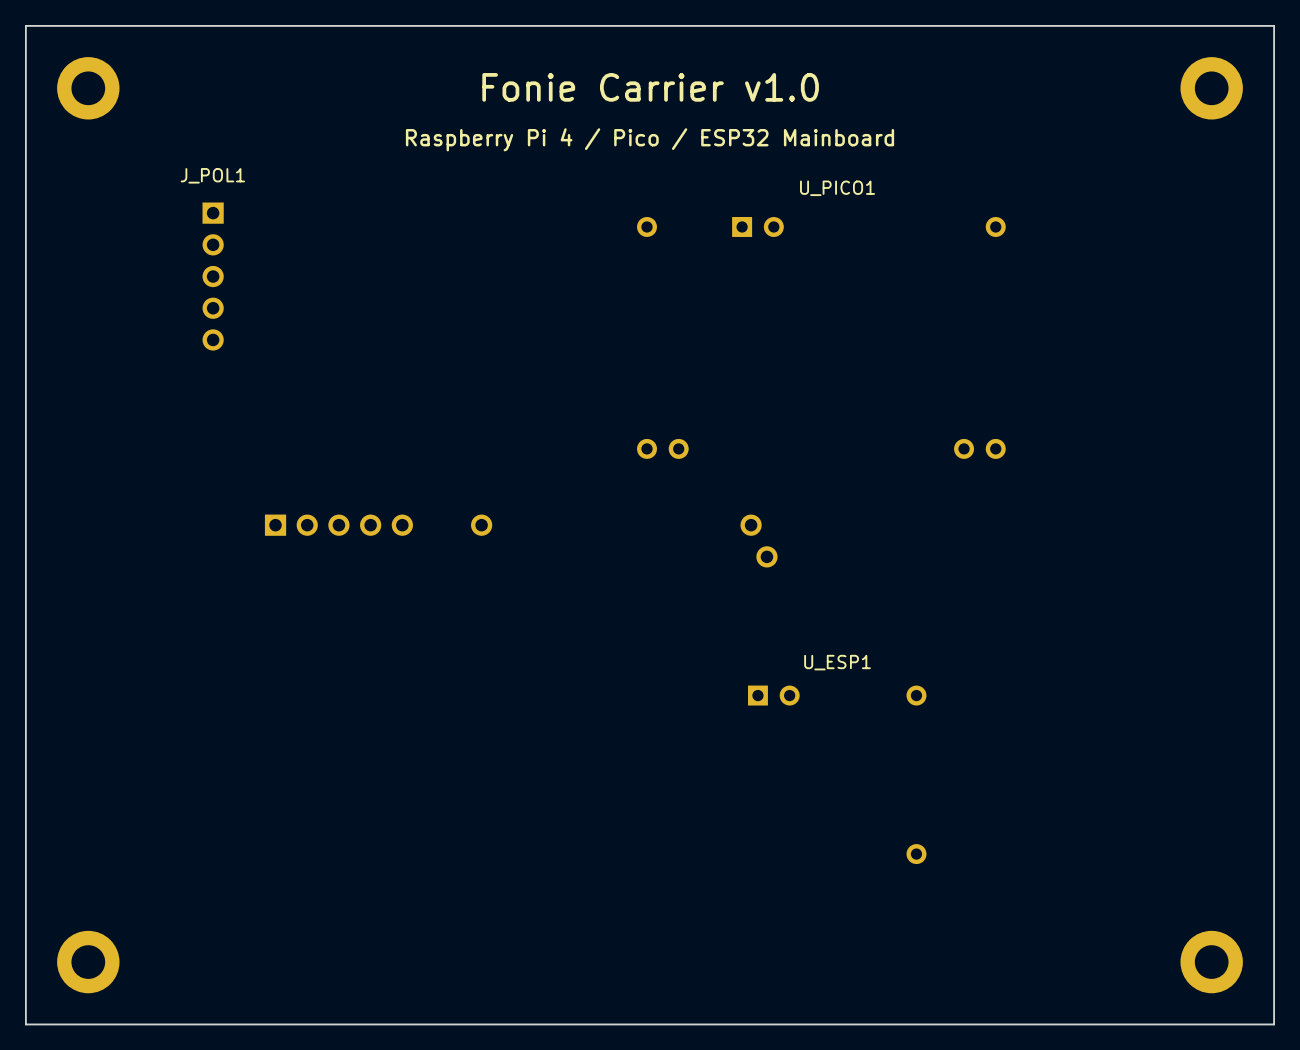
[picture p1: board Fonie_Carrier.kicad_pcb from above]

Board: 2 copper layers, 100.0 x 80.0 mm, 4 parts (1 on the bottom side), 9 nets, no tracks yet.

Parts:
J_PI1: Pi4_GPIO; IDC-Header_2x20_P2.54mm_Vertical
J_POL1: Pololu2808; PinHeader_1x05_P2.54mm_Vertical
U_ESP1: ESP32-C3; ESP32-C3_SuperMini
U_PICO1: RP2040_Zero; Waveshare_RP2040_Zero

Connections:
+5V: J_PI1.2, J_PI1.4, J_POL1.3, U_ESP1.5V, U_PICO1.5V
GND: J_PI1.6, J_POL1.2, U_ESP1.GND, U_PICO1.GND
PI_ESP_RX: J_PI1.33, U_ESP1.21
PI_ESP_TX: J_PI1.32, U_ESP1.20
PI_PICO_RX: J_PI1.10, U_PICO1.0
PI_PICO_TX: J_PI1.8, U_PICO1.1
POLOLU_A: J_POL1.4, U_PICO1.26
POLOLU_OFF: J_POL1.5, U_PICO1.14
SHUTDOWN_SENSE: J_PI1.15, U_PICO1.8

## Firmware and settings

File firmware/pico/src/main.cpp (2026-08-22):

#include <Adafruit_NeoPixel.h>
#include <Wire.h>
#include <Updater.h>
#include <LittleFS.h>
#include <Wire.h>
#include "hardware/watchdog.h"
#include "hardware/structs/watchdog.h"

// ── Pin config ────────────────────────────────────────────────────────────────
#define RGB_PIN     16
#define RING_PIN     2
#define MATRIX_PIN   3
#define STRIPL_PIN   4
#define STRIPR_PIN   5
#define RING_LEDS   24
#define MATRIX_LEDS 64
#define STRIP_LEDS  26

#define POLOLU_OFF_PIN 14

// INA226 I2C (same pins as old MAX17043)
#define INA226_ADDR 0x40
#define INA226_SDA  6
#define INA226_SCL  7

// INA226 registers
#define INA226_REG_CONFIG    0x00
#define INA226_REG_SHUNT     0x01
#define INA226_REG_BUS       0x02
#define INA226_REG_CALIB     0x05

// Shunt resistor value (R002 = 2mΩ = 0.002Ω)
#define SHUNT_OHMS        0.002f
// Pack capacity in mAh (3 x 2900mAh in series)
#define PACK_CAPACITY_MAH 2900.0f
// Current sense LSB with R002 shunt: 2.5uV / 0.002Ω = 1.25mA per LSB
#define CURRENT_LSB_MA    1.25f
// Bus voltage LSB is 1.25mV; calibrated scale factor matches physical multimeter reading (12.70V / 12.233V)
#define BUS_VOLTAGE_LSB      0.00125f // V per LSB
#define VOLTAGE_CALIB_SCALE  1.038168f // Calibrates VBUS pin reading to multimeter 12.70V

// 3S pack voltage thresholds
#define PACK_FULL_V          12.60f   // Standard 3S Li-ion full voltage (4.20V/cell)
#define PACK_EMPTY_V          9.00f   // 3.0V per cell
#define PACK_REST_I_MA       50.00f   // below this = at rest (no significant load/charge)
#define CHARGE_TAPER_MA      150.00f  // CV phase taper threshold → set SoC = 100%

#define FIRMWARE_VERSION "1.2.0"

// Buttons (INPUT_PULLDOWN, HIGH when pressed)
#define BTN_PREV    29
#define BTN_PLAY    28
#define BTN_NEXT    27
#define BTN_VOLUP   26
#define BTN_VOLDOWN 15

#define PI_SHUTDOWN_SENSE_PIN 8

#define DEBOUNCE_MS  50
#define VOL_STEP      5
#define VOL_MIN       0
#define VOL_MAX     100

Adafruit_NeoPixel rgb(1,            RGB_PIN,    NEO_GRB + NEO_KHZ800);
Adafruit_NeoPixel ring(RING_LEDS,   RING_PIN,   NEO_GRB + NEO_KHZ800);
Adafruit_NeoPixel matrix(MATRIX_LEDS, MATRIX_PIN, NEO_GRB + NEO_KHZ800);
Adafruit_NeoPixel stripL(STRIP_LEDS, STRIPL_PIN, NEO_GRBW + NEO_KHZ800);
Adafruit_NeoPixel stripR(STRIP_LEDS, STRIPR_PIN, NEO_GRBW + NEO_KHZ800);

// ── State machine ─────────────────────────────────────────────────────────────
enum State { S_OFF, S_TAG_ON_BURST, S_PLAYING, S_PAUSED, S_TAG_OFF_FADE, S_VOLUME, S_BOOTING, S_SHUTDOWN, S_LED_TEST, S_IDLE, S_WIFI_AP, S_TAG_TEXT_SCROLL };
State currentState   = S_BOOTING;
State preVolumeState = S_OFF;

// Vol Up button long-press tracking (for Pololu soft switch OFF trigger)
unsigned long volUpPressStart = 0;
bool volUpHeld = false;
bool shutdownInitiated = false;

// Pi shutdown polling state
unsigned long lastPiPingSent = 0;
unsigned long lastPiResponseTime = 0;
bool piNoResponseDetected = false;
unsigned long noResponseStartTime = 0;
bool ledsCleared = false;

unsigned long stateStart = 0;
unsigned long lastFrame  = 0;

void reportSoC();
String extractValue(const String& json, const String& key);
float   spinPos    = 0.0;
float   breathVal  = 1.0;
int     breathDir  = -1;
float   fadeVal    = 1.0;
int     volumeLevel = 80;
uint8_t animR = 0, animG = 200, animB = 200;
uint8_t animR2 = 0, animG2 = 180, animB2 = 255;
String animMode = "equalizer";
float animSpeed = 1.0f;
float   waveOffset = 0.0;

// ── SoC / INA226 state ────────────────────────────────────────────────────────
float   socPercent   = 50.0f;  // initial guess until we correct from voltage
bool    socValid     = false;
float   packVoltage  = 0.0f;
float   packCurrentMA = 0.0f;  // positive = discharging, negative = charging
bool    isCharging   = false;
bool    lastCharging = false;

unsigned long lastSoCRead    = 0;
unsigned long lastSoCReport  = 0;
unsigned long lastRestStart  = 0;
bool          atRest         = false;

#define SOC_READ_INTERVAL_MS    500    // read INA226 every 500ms
#define SOC_REPORT_INTERVAL_MS  2000   // report to Pi every 2s

// ── Buttons ───────────────────────────────────────────────────────────────────
struct Button {
  uint8_t pin;
  const char* name;
  bool state;
  bool lastRaw;
  unsigned long lastChange;
};

Button buttons[] = {
  { BTN_PREV,    "prev",   false, false, 0 },
  { BTN_PLAY,    "play",   false, false, 0 },
  { BTN_NEXT,    "next",   false, false, 0 },
  { BTN_VOLUP,   "vol_up", false, false, 0 },
  { BTN_VOLDOWN, "vol_dn", false, false, 0 },
};
#define NUM_BUTTONS 5

// ── INA226 ────────────────────────────────────────────────────────────────────
void reportSoC();
void ina226_writeReg(uint8_t reg, uint16_t val) {
  Wire1.beginTransmission(INA226_ADDR);
  Wire1.write(reg);
  Wire1.write((val >> 8) & 0xFF);
  Wire1.write(val & 0xFF);
  Wire1.endTransmission();
}

uint16_t ina226_readReg(uint8_t reg) {
  Wire1.beginTransmission(INA226_ADDR);
  Wire1.write(reg);
  Wire1.endTransmission(false);
  Wire1.requestFrom(INA226_ADDR, 2);
  if (Wire1.available() < 2) return 0;
  uint16_t val = (Wire1.read() << 8) | Wire1.read();
  return val;
}

void ina226_init() {
  Wire1.setSDA(INA226_SDA);
  Wire1.setSCL(INA226_SCL);
  Wire1.begin();

  // Config: avg 16 samples, 1.1ms conversion, continuous shunt+bus
  // BADC=SADC=0b0101 (1.1ms), AVG=0b011 (16), MODE=111 (continuous)
  ina226_writeReg(INA226_REG_CONFIG, 0x4527);

  // Calibration register: Cal = 0.00512 / (CurrentLSB * Rshunt)
  // CurrentLSB = 0.025mA = 0.000025A
  // Cal = 0.00512 / (0.000025 * 0.1) = 2048
  ina226_writeReg(INA226_REG_CALIB, 25600);

  Serial.println("INA226 init done");
}

bool ina226_scan() {
  Wire1.beginTransmission(INA226_ADDR);
  return Wire1.endTransmission() == 0;
}

// Returns bus voltage in volts
float ina226_voltage() {
  uint16_t raw = ina226_readReg(INA226_REG_BUS);
  return (raw * BUS_VOLTAGE_LSB) * VOLTAGE_CALIB_SCALE;
}

// Returns current in mA (positive = discharging, negative = charging)
float ina226_current() {
  int16_t raw = (int16_t)ina226_readReg(INA226_REG_SHUNT);
  // Shunt register LSB = 2.5uV
  // Current = (raw * 2.5uV) / Rshunt
  float shuntVoltage_uV = raw * 2.5f;
  return (shuntVoltage_uV / 1000.0f) / SHUNT_OHMS;
}

// ── SoC from OCV curve (3S NCA Li-ion, rest state only) ──────────────────────
// 11-point lookup table at 10% SoC intervals, voltages in V for 3S pack
// Based on standard NCA OCV curve (BAK N18650CL-29 type)
static const float OCV_V[11] = {
   9.00f,  // 0%
   9.84f,  // 10%
  10.50f,  // 20%
  10.86f,  // 30%
  11.10f,  // 40%
  11.25f,  // 50%
  11.40f,  // 60%
  11.55f,  // 70%
  11.76f,  // 80%
  12.06f,  // 90%
  12.60f,  // 100% (4.20V per cell)
};

float voltageToSoC(float v) {
  // Deduct internal resistance voltage drop during charging (I * 0.10 ohm)
  float v_ocv = isCharging ? (v - (abs(packCurrentMA) / 1000.0f) * 0.10f) : v;
  if (v_ocv <= OCV_V[0])  return 0.0f;
  if (v_ocv >= OCV_V[10]) return 100.0f;
  for (int i = 0; i < 10; i++) {
    if (v_ocv <= OCV_V[i + 1]) {
      float t = (v_ocv - OCV_V[i]) / (OCV_V[i + 1] - OCV_V[i]);
      return (i + t) * 10.0f;
    }
  }
  return 100.0f;
}

// ── SoC persistence (LittleFS) ────────────────────────────────────────────────
static float lastSavedSoC = -1.0f;

void saveSoC() {
  if (abs(socPercent - lastSavedSoC) >= 1.0f) {
    lastSavedSoC = socPercent;
    File f = LittleFS.open("/soc.json", "w");
    if (f) {
      f.printf("{\"soc\":%.1f}", socPercent);
      f.close();
    }
  }
}

void loadSoC() {
  packVoltage = ina226_voltage();
  socPercent  = voltageToSoC(packVoltage);
  lastSavedSoC = socPercent;
  socValid    = true;
  Serial.printf("Initial SoC from calibrated voltage: %.1f%%\n", socPercent);
}

// ── Volume persistence (LittleFS) ─────────────────────────────────────────────
static int lastSavedVolume = -1;

void saveVolume(int vol) {
  vol = constrain(vol, VOL_MIN, VOL_MAX);
  volumeLevel = vol;
  if (volumeLevel != lastSavedVolume) {
    lastSavedVolume = volumeLevel;
    File f = LittleFS.open("/vol.json", "w");
    if (f) {
      f.printf("{\"vol\":%d}", volumeLevel);
      f.close();
      Serial.printf("Saved volume to LittleFS: %d\n", volumeLevel);
    }
  }
}

void loadVolume() {
  if (LittleFS.exists("/vol.json")) {
    File f = LittleFS.open("/vol.json", "r");
    if (f) {
      String content = f.readString();
      f.close();
      int val = extractValue(content, "vol").toInt();
      if (val >= VOL_MIN && val <= VOL_MAX) {
        volumeLevel = val;
        lastSavedVolume = volumeLevel;
        Serial.printf("Loaded persistent volume from LittleFS: %d\n", volumeLevel);
        return;
      }
    }
  }
  volumeLevel = 80;
  lastSavedVolume = 80;
}

// ── SoC update (coulomb counting + correction) ────────────────────────────────
void updateSoC() {
  unsigned long now = millis();
  if (now - lastSoCRead < SOC_READ_INTERVAL_MS) return;

  float dt_h = (now - lastSoCRead) / 3600000.0f;  // ms to hours
  lastSoCRead = now;

  packVoltage   = ina226_voltage();
  if (packVoltage == 0.0f) {
    ina226_init();
    packVoltage = ina226_voltage();
  }
  packCurrentMA = ina226_current();
  isCharging    = packCurrentMA < -PACK_REST_I_MA;

  // Immediate report on charging state change
  if (isCharging != lastCharging) {
    lastCharging = isCharging;
    socValid = true;
    reportSoC();
  }

  // Coulomb counting: discharge = positive current = decreases SoC
  // charge = negative current = increases SoC
  float deltaSoC = (-packCurrentMA * dt_h / PACK_CAPACITY_MAH) * 100.0f;
  socPercent = constrain(socPercent + deltaSoC, 0.0f, 100.0f);

  // Rest state detection (ONLY when not charging)
  if (!isCharging && abs(packCurrentMA) < PACK_REST_I_MA) {
    if (!atRest) { atRest = true; lastRestStart = now; }
    // Correct from voltage after 30s at rest
    if (now - lastRestStart > 30000) {
      float voltSoC = voltageToSoC(packVoltage);
      // Gentle correction — blend toward voltage-based SoC
      socPercent = socPercent * 0.7f + voltSoC * 0.3f;
      Serial.print("OCV correction: ");
      Serial.print(voltSoC, 1); Serial.println("%");
    }
  } else {
    atRest = false;
    lastRestStart = now;
  }

  // Full charge anchor: High voltage (>=12.45V) + tapering/low current
  if (packVoltage >= 12.45f && abs(packCurrentMA) < CHARGE_TAPER_MA) {
    socPercent = 100.0f;
    Serial.println("Full charge / CV taper detected -> SoC = 100%");
  }

  // Empty anchor
  if (packVoltage <= PACK_EMPTY_V + 0.1f && !isCharging) {
    socPercent = 0.0f;
  }

  // Save to LittleFS if changed
  saveSoC();

  // Report to Pi periodically
  if (now - lastSoCReport >= SOC_REPORT_INTERVAL_MS || !socValid) {
    socValid = true;
    reportSoC();
  }
}

void reportSoC() {
  lastSoCReport = millis();
  String msg = "{\"event\":\"SOC\""
               ",\"version\":\"" FIRMWARE_VERSION "\""
               ",\"level\":"    + String((int)socPercent) +
               ",\"voltage\":"  + String(packVoltage, 3) +
               ",\"current\":"  + String(packCurrentMA, 1) +
               ",\"charging\":" + (isCharging ? "true" : "false") + "}";
  Serial1.println(msg);
  Serial.println(msg);
}

// ── 5x3 pixel font ────────────────────────────────────────────────────────────
const uint8_t digitFont[10][5] = {
  {0b111,0b101,0b101,0b101,0b111},{0b010,0b110,0b010,0b010,0b111},
  {0b111,0b001,0b111,0b100,0b111},{0b111,0b001,0b111,0b001,0b111},
  {0b101,0b101,0b111,0b001,0b001},{0b111,0b100,0b111,0b001,0b111},
  {0b111,0b100,0b111,0b101,0b111},{0b111,0b001,0b001,0b001,0b001},
  {0b111,0b101,0b111,0b101,0b111},{0b111,0b101,0b111,0b001,0b111},
};

const uint8_t letterFont[26][5] = {
  {0b010,0b101,0b111,0b101,0b101}, // A
  {0b110,0b101,0b110,0b101,0b110}, // B
  {0b011,0b100,0b100,0b100,0b011}, // C
  {0b110,0b101,0b101,0b101,0b110}, // D
  {0b111,0b100,0b110,0b100,0b111}, // E
  {0b111,0b100,0b110,0b100,0b100}, // F
  {0b011,0b100,0b101,0b101,0b011}, // G
  {0b101,0b101,0b111,0b101,0b101}, // H
  {0b111,0b010,0b010,0b010,0b111}, // I
  {0b001,0b001,0b001,0b101,0b010}, // J
  {0b101,0b101,0b110,0b101,0b101}, // K
  {0b100,0b100,0b100,0b100,0b111}, // L
  {0b101,0b111,0b101,0b101,0b101}, // M
  {0b101,0b111,0b111,0b101,0b101}, // N
  {0b010,0b101,0b101,0b101,0b010}, // O
  {0b110,0b101,0b110,0b100,0b100}, // P
  {0b010,0b101,0b101,0b110,0b011}, // Q
  {0b110,0b101,0b110,0b101,0b101}, // R
  {0b011,0b100,0b010,0b001,0b110}, // S
  {0b111,0b010,0b010,0b010,0b010}, // T
  {0b101,0b101,0b101,0b101,0b011}, // U
  {0b101,0b101,0b101,0b101,0b010}, // V
  {0b101,0b101,0b101,0b111,0b101}, // W
  {0b101,0b101,0b010,0b101,0b101}, // X
  {0b101,0b101,0b010,0b010,0b010}, // Y
  {0b111,0b001,0b010,0b100,0b111}  // Z
};

// ── Matrix helpers ────────────────────────────────────────────────────────────
int matrixPixel(int x, int y) {
  int rx = y;
  int ry = 7 - x;
  return (ry % 2 == 0) ? ry * 8 + rx : ry * 8 + (7 - rx);
}
void matrixSet(int x, int y, uint8_t r, uint8_t g, uint8_t b) {
  if (x < 0 || x >= 8 || y < 0 || y >= 8) return;
  matrix.setPixelColor(matrixPixel(x, y), matrix.Color(r, g, b));
}
void matrixClear() {
  matrix.clear();
  matrix.show();
}

void drawChar5x3(char c, int startX, int startY, uint8_t r, uint8_t g, uint8_t b) {
  c = toupper(c);
  const uint8_t* rows = nullptr;
  if (c >= '0' && c <= '9') rows = digitFont[c - '0'];
  else if (c >= 'A' && c <= 'Z') rows = letterFont[c - 'A'];
  if (!rows) return;
  for (int row = 0; row < 5; row++) {
    uint8_t bits = rows[row];
    for (int col = 0; col < 3; col++)
      if (bits & (1 << (2 - col))) matrixSet(startX + col, startY + (4 - row), r, g, b);
  }
}

void drawDigit(int d, int startX, int startY, uint8_t r, uint8_t g, uint8_t b) {
  drawChar5x3(d + '0', startX, startY, r, g, b);
}

void drawSoC(int soc) {
  return;
}

// ── Matrix animations ─────────────────────────────────────────────────────────
void drawVolumeBar(int vol) {
  matrixClear();
  int cols = (vol * 8) / 100;
  for (int x = 0; x < cols; x++) {
    uint8_t r, g, b = 0;
    if (x < 4) { r = (uint8_t)(x * 60); g = 255; }
    else        { r = 255; g = (uint8_t)(255 - ((x - 4) * 60)); }
    for (int y = 0; y < 8; y++) matrixSet(x, y, r, g, b);
  }
  matrix.show();
}

void drawMatrixWave(uint8_t r, uint8_t g, uint8_t b) {
  matrixClear();
  for (int x = 0; x < 8; x++) {
    float phase  = waveOffset + (x * 0.8);
    float s      = (sin(phase) + 1.0) / 2.0;
    int litRows  = (int)(s * 8);
    int startRow = (8 - litRows) / 2;
    for (int y = startRow; y < startRow + litRows; y++) {
      float rowFade = 1.0 - abs((y - 3.5) / 4.0) * 0.5;
      matrixSet(x, y, (uint8_t)(r*rowFade), (uint8_t)(g*rowFade), (uint8_t)(b*rowFade));
    }
  }
  matrix.show();
}

void drawMatrixCheckerboard(uint8_t r, uint8_t g, uint8_t b) {
  matrixClear();
  matrix.show();
}

void drawMatrixBurst(float progress, uint8_t r, uint8_t g, uint8_t b) {
  matrixClear();
  float dist = progress * 5.66;
  for (int x = 0; x < 8; x++) {
    for (int y = 0; y < 8; y++) {
      float dx = x - 3.5, dy = y - 3.5;
      float d  = sqrt(dx*dx + dy*dy);
      if (d <= dist) {
        float df = 1.0 - (d / dist) * 0.5;
        matrixSet(x, y, (uint8_t)(r*df), (uint8_t)(g*df), (uint8_t)(b*df));
      }
    }
  }
  matrix.show();
}

void drawMatrixSolid(uint8_t r, uint8_t g, uint8_t b) {
  for (int i = 0; i < MATRIX_LEDS; i++)
    matrix.setPixelColor(i, matrix.Color(r, g, b));
  matrix.show();
}

void drawMatrixSpin(float angle, uint8_t r, uint8_t g, uint8_t b) {
  matrixClear();
  for (int x = 0; x < 8; x++) {
    for (int y = 0; y < 8; y++) {
      float dx = x - 3.5f;
      float dy = y - 3.5f;
      float dist = sqrt(dx*dx + dy*dy);
      if (dist > 4.2f) continue;
      float a = atan2(dy, dx);
      float diff = a - angle;
      while (diff < 0) diff += 2.0f * M_PI;
      while (diff >= 2.0f * M_PI) diff -= 2.0f * M_PI;
      float norm = diff / (2.0f * M_PI);
      float tail = pow(1.0f - norm, 2.5f);
      matrixSet(x, y, (uint8_t)(r * tail), (uint8_t)(g * tail), (uint8_t)(b * tail));
    }
  }
  matrix.show();
}

void drawRingSpin(float angle, uint8_t r, uint8_t g, uint8_t b) {
  ring.clear();
  int lead = (int)((angle / (2.0f * M_PI)) * RING_LEDS) % RING_LEDS;
  if (lead < 0) lead += RING_LEDS;
  for (int i = 0; i < 8; i++) {
    int idx = (lead - i + RING_LEDS) % RING_LEDS;
    float fade = pow(1.0f - ((float)i / 8.0f), 2.0f);
    ring.setPixelColor(idx, ring.Color((uint8_t)(r * fade), (uint8_t)(g * fade), (uint8_t)(b * fade)));
  }
  ring.show();
}

// ── Helpers ───────────────────────────────────────────────────────────────────
void setRGB(uint8_t r, uint8_t g, uint8_t b) {
  rgb.setPixelColor(0, rgb.Color(r, g, b)); rgb.show();
}
void allOff() {
  ring.clear(); ring.show(); 
  matrixClear(); matrix.show(); 
  stripL.clear(); stripL.show();
  stripR.clear(); stripR.show();
  setRGB(0,0,0);
}

float playFadeIn = 1.0f;

void setState(State s) {
  currentState = s;
  stateStart   = millis();
  lastFrame    = millis();
  if (s == S_OFF)          allOff();
  if (s == S_TAG_OFF_FADE) fadeVal   = 1.0;
  if (s == S_PLAYING)      { spinPos = 0; breathVal = 1.0; breathDir = -1; waveOffset = 0; playFadeIn = 0.0f; }
  if (s == S_PAUSED)       { breathVal = 1.0; breathDir = -1; }
  if (s == S_SHUTDOWN) {
    lastPiPingSent = 0;
    lastPiResponseTime = millis();
    piNoResponseDetected = false;
    noResponseStartTime = 0;
    ledsCleared = false;
    ring.setBrightness(255);
    matrix.setBrightness(255);
    stripL.setBrightness(255);
    stripR.setBrightness(255);
  }
}

void overlaySoC() {
  if (!socValid) return;
  drawSoC((int)socPercent);
}
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
void loop() {
  watchdog_update();

  if (digitalRead(PI_SHUTDOWN_SENSE_PIN) == HIGH && currentState != S_SHUTDOWN) {
    Serial.println("Pico: Emergency PI_SHUTDOWN_SENSE_PIN HIGH detected. Driving POLOLU_OFF_PIN HIGH!");
    digitalWrite(POLOLU_OFF_PIN, HIGH);
    while (1) { delay(10); }
  }
  // Animation frame ~60fps
  if (millis() - lastFrame >= 16) {
    lastFrame = millis();
    switch (currentState) {
      case S_BOOTING:          frameBooting(); break;
      case S_TAG_ON_BURST:     frameBurst();   break;
      case S_TAG_TEXT_SCROLL:  frameTextScroll(); break;
      case S_PLAYING:          framePlaying(); break;
      case S_PAUSED:           framePaused();  break;
      case S_TAG_OFF_FADE:     frameFade();    break;
      case S_VOLUME:           frameVolume();  break;
      case S_OFF:              frameOff();     break;
      case S_SHUTDOWN:         frameShutdown(); break;
      case S_LED_TEST:         frameLedTest(); break;
      case S_WIFI_AP:           frameWifiAp();  break;
      case S_IDLE:             allOff();       break;
    }
  }

  // SoC update
  updateSoC();

  // Buttons
  pollButtons();

  // UART from Pi
  while (Serial1.available()) {
    char c = (char)Serial1.read();
    if (c == '\n') {
      inputBuffer.trim();
      int startIdx = inputBuffer.lastIndexOf('{');
      if (startIdx >= 0) {
        inputBuffer = inputBuffer.substring(startIdx);
      }
      if (inputBuffer.length() > 0) handleEvent(inputBuffer);
      inputBuffer = "";
    } else {
      inputBuffer += c;
      if (inputBuffer.length() > 128) {
        inputBuffer = ""; // Prevent memory exhaustion from UART noise during shutdown
      }
    }
  }
}

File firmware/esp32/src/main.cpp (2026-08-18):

#include <SPI.h>
#include <Wire.h>
#include <PN532_I2C.h>
#include <PN532.h>
#include <WiFi.h>
#include <WebServer.h>
#include <DNSServer.h>
#include <ArduinoOTA.h>
#include <ArduinoJson.h>
#include <LittleFS.h>
#include <ESPmDNS.h>

#define SDA_PIN 3
#define SCL_PIN 4
#define RPI_TX  21   // ESP32 TX → Pi RX
#define RPI_RX  20   // ESP32 RX ← Pi TX

#define FIRMWARE_VERSION "1.1.3"

PN532_I2C pn532_i2c(Wire);
PN532 nfc(pn532_i2c);
HardwareSerial RpiSerial(1);   // UART1

const unsigned long POLL_INTERVAL_MS = 50;
const int MAX_MISSED_READS           = 3; // 3 consecutive misses (~150ms) triggers TAG_OFF

bool inApMode = false;
bool inStaMode = false;
bool otaStarted = false;
bool pn532_connected = false;
bool tagPresent = false;
int missedReads = 0;
String currentUid = "";
unsigned long lastSeen = 0, lastPoll = 0;

// Wi-Fi / Captive Portal State
const byte DNS_PORT = 53;
DNSServer dnsServer;
WebServer server(80);
String uidToString(uint8_t *uid, uint8_t len) {
  String s;
  for (uint8_t i = 0; i < len; i++) { if (uid[i] < 0x10) s += "0"; s += String(uid[i], HEX); }
  s.toUpperCase(); return s;
}

// -- Captive Portal Handlers --
void handleRoot() {
  if (LittleFS.exists("/index.html")) {
    File file = LittleFS.open("/index.html", "r");
    server.streamFile(file, "text/html");
    file.close();
  } else {
    server.send(500, "text/plain", "Error: index.html not found in LittleFS. Did you upload the File System Image?");
  }
}

void handleScan() {
  int n = WiFi.scanNetworks();
  JsonDocument doc;
  JsonArray array = doc.to<JsonArray>();
  for (int i = 0; i < n; ++i) {
    JsonObject obj = array.add<JsonObject>();
    obj["ssid"] = WiFi.SSID(i);
    obj["rssi"] = WiFi.RSSI(i);
    obj["secure"] = WiFi.encryptionType(i) != WIFI_AUTH_OPEN;
  }
  String json;
  serializeJson(doc, json);
  server.send(200, "application/json", json);
}

void handleSave() {
  String ssid = server.arg("ssid");
  String pass = server.arg("pass");
  
  // Send back to Pi
  JsonDocument doc;
  doc["event"] = "WIFI_CONFIG";
  doc["ssid"] = ssid;
  doc["pass"] = pass;
  String out;
  serializeJson(doc, out);
  
  // Flush UART and delay slightly to ensure transmission isn't corrupted
  RpiSerial.println(out);
  RpiSerial.flush();
  delay(10);
  
  Serial.println("Sent WIFI_CONFIG to Pi: " + ssid);

  server.send(200, "application/json", "{\"status\":\"ok\"}");
}

void startAP() {
  if (inApMode) return;
  
  Serial.println("Starting Captive Portal AP: Fonie-Setup");
  
  // Robust Wi-Fi AP Initialization for ESP32-C3
  WiFi.disconnect(true, true);
  delay(100);
  WiFi.mode(WIFI_AP);
  
  // Workaround for some C3 boards browning out or failing RF calibration
  WiFi.setTxPower(WIFI_POWER_8_5dBm);
  
  // Start AP on channel 1, no password, max 4 connections
  bool success = WiFi.softAP("Fonie-Setup", NULL, 1, 0, 4);
  
  if (success) {
    Serial.print("AP started successfully! IP Address: ");
    Serial.println(WiFi.softAPIP());
  } else {
    Serial.println("FAILED to start AP!");
  }
  
  dnsServer.start(DNS_PORT, "*", WiFi.softAPIP());
  
  server.on("/", HTTP_GET, handleRoot);
  server.on("/scan", HTTP_GET, handleScan);
  server.on("/save", HTTP_POST, handleSave);
  server.onNotFound(handleRoot); // Redirect all to root
  server.begin();
  
  inApMode = true;
  inStaMode = false;
}

void startSTA(const char* ssid, const char* pass) {
  if (inApMode) {
    dnsServer.stop();
    server.stop();
    inApMode = false;
  }
  Serial.printf("Connecting to Wi-Fi STA: %s\n", ssid);
  WiFi.disconnect(true);
  delay(50);
  WiFi.mode(WIFI_STA);
  WiFi.setHostname("fonie-esp32");
  WiFi.begin(ssid, pass);
  inStaMode = true;
  otaStarted = false;
}

void setup() {
  Serial.begin(115200);                                    // USB debug
  unsigned long startWait = millis();
  while (!Serial && millis() - startWait < 4000) {
    delay(10); // Wait up to 4s for serial monitor to connect
  }
  Serial.println("\n\n--- Fonie ESP32 Booting ---");
  RpiSerial.begin(115200, SERIAL_8N1, RPI_RX, RPI_TX);   // UART to Pi

  if (!LittleFS.begin(true)) {
    Serial.println("LittleFS Mount Failed");
  } else {
    Serial.println("LittleFS Mounted Successfully");
  }

  Wire.begin(SDA_PIN, SCL_PIN);
  nfc.begin();
  if (!nfc.getFirmwareVersion()) {
    Serial.println("No PN532 found. Running in UART-only mode.");
    RpiSerial.println("{\"event\":\"ERROR\",\"msg\":\"No PN532 found\"}");
    pn532_connected = false;
  } else {
    nfc.SAMConfig();
    Serial.println("PN532 ready");
    pn532_connected = true;
  }
  RpiSerial.println("{\"event\":\"READY\",\"version\":\"" FIRMWARE_VERSION "\"}");
  Serial.println("ESP32 ready and listening");
}

void handleSerialCommand(const String& cmd) {
  if (cmd.indexOf("\"event\":\"PING\"") >= 0 || cmd.indexOf("\"event\": \"PING\"") >= 0) {
    Serial.println("Received PING");
    RpiSerial.println("{\"event\":\"PONG\",\"version\":\"" FIRMWARE_VERSION "\"}");
    Serial.println("{\"event\":\"PONG\"}");
  } 
  else if (cmd.indexOf("WIFI_AP_START") >= 0) {
    Serial.println("Received WIFI_AP_START, attempting startAP()...");
    RpiSerial.println("{\"event\":\"DEBUG\",\"msg\":\"ESP32: Received WIFI_AP_START\"}");
    startAP();
    RpiSerial.println("{\"event\":\"DEBUG\",\"msg\":\"ESP32: startAP() finished\"}");
  }
  else if (cmd.indexOf("WIFI_CONNECT") >= 0) {
    Serial.println("Received WIFI_CONNECT");
    JsonDocument doc;
    DeserializationError error = deserializeJson(doc, cmd);
    if (!error) {
      const char* ssid = doc["ssid"] | "";
      const char* pass = doc["pass"] | "";
      startSTA(ssid, pass);
    } else {
      Serial.println("Failed to parse WIFI_CONNECT JSON");
    }
  }
}
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

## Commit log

2026-02-26 Commit before adding extra UART
2026-03-20 Working version before adding buttons
2026-05-16 Monorepo restructuring and UART Ping/Pong mechanism
2026-08-15 feat: add 5-band sound equalizer, audio enhancements, custom startup/shutdown audio, and LED unit test animations
2026-08-18 style: add smooth 600ms LED fade-out animation before power cutoff
2026-08-18 style: increase shutdown LED fade-out duration from 600ms to 2000ms
2026-08-18 fix: switch web interface from HTTPS port 5000 to standard HTTP port 80
2026-08-20 docs: add carrier PCB design specification and KiCad netlist
2026-08-20 feat: generate KiCad v7/v8 project, schematic, and PCB layout files in pcb/
    [Fonie_Carrier.kicad_pcb, Fonie_Carrier.kicad_sch]
2026-08-21 feat: add S_WIFI_AP electric cyan beacon LED pattern and fallback audio notification
2026-08-21 fix: enable instant track switching from web UI with audio format s32, fast mpv stop, and playlist rotation
    [app.py]
2026-08-21 feat: render track buttons on mapping cards for single-click track selection
2026-08-21 fix: add force_ap_mode override in app.py to keep AP open when manually triggered
    [app.py]
2026-08-21 fix: adjust manual AP override window to 60 seconds
    [app.py]
2026-08-21 fix: set pico_is_alive and esp32_is_alive to True on successful serial connection
    [app.py]
2026-08-21 fix: upgrade yt-dlp, add youtube player_client args, and document version bumping routine
    [app.py]
2026-08-21 feat: add real-time download progress_hooks and fix MCU version reporting
    [app.py, main.cpp]
2026-08-21 fix: hide 0% battery pill on Web UI, rotate matrix 90deg CCW, and refine Pico idle/fade transitions
    [app.py, main.cpp, pico_uart_flash.py]
2026-08-22 feat: add character name editing endpoint & Edit Name button on mapping cards
2026-08-22 feat: render prominent + Character Name / 🎭 [Name] badge button on every card
2026-08-22 fix: import make_response from flask in app.py
    [app.py]
2026-08-22 feat: place Character Name button in card-actions next to Delete
2026-08-22 fix: invert character row mapping in drawChar5x3 for right-side-up matrix text scroller
    [main.cpp]
2026-08-22 fix: defer S_PLAYING transition until S_TAG_TEXT_SCROLL animation finishes
    [main.cpp]
2026-08-22 feat: add smooth audio fade-in/out and protect LED show & text scroll on tag resume
2026-08-22 feat: add individual track deletion and manual Tag UID re-keying for mappings
2026-08-22 feat: add Deluxe Edit Controls Modal for Tag UID re-keying, metadata, and track deletion
